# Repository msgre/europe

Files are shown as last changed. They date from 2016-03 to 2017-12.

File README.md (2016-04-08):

Europe is interactive knowledge game for children.

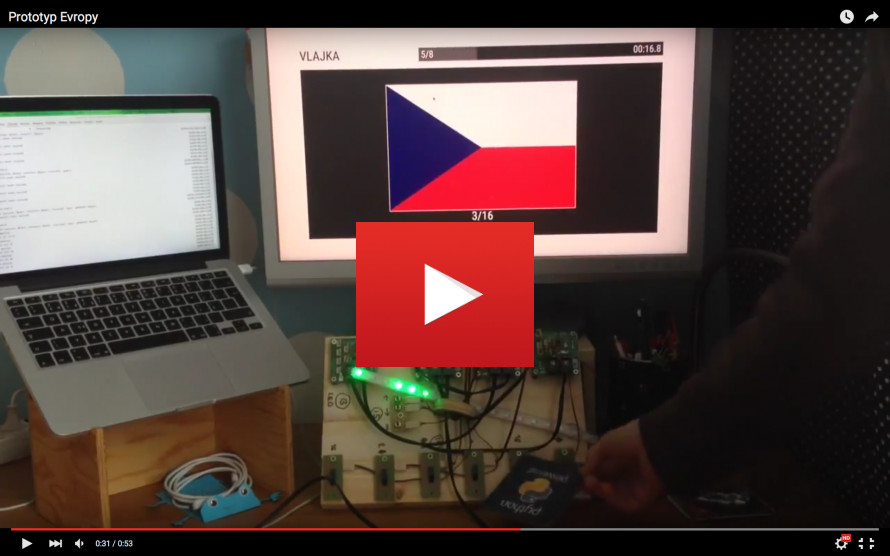
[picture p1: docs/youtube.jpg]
Europe prototype (https://youtu.be/zgLyUA2WT7c)


**Content**:

* [Construction](#construction)
    * [Gameboard](#gameboard)
    * [Hardware](#hardware)
    * [Software](#software)
    * [Design](#design)
    * [Content](#content)
* [Docker](#docker)
    * [Build](#build)
    * [Run](#run)
* [Application](#application)
    * [Game interface](#game-interface)
    * [Administration interface](#administration-interface)
* [Notes](#notes)
    * [Database initialization](#database-initialization)
    * [Coffeescript compilation](#coffeescript-compilation)
    * [LESS compilation](#less-compilation)
    * [Debug mode for Javascript application](#debug-mode-for-javascript-application)

# Construction

It is constructed from several parts:

* big wooden gameboard with map of Europe
* bunch of electronics
* software

## Gameboard

Board will be connected to the ground via spring, so children will be able to 
tilt it. Each european country will have gate on his territory. 

## Hardware

Each gate is constructed as optical sensor. On bottom part of board is 10
control boards, each of them capable to read state up to 6 sensors. Boards are
interconnected via ModBus.

There are additional 2 special boards -- one of them will serve as keyboard
(instead of optical sensors it will read state from buttons), second as 
controller of Neopixels RGB LED.

Details about hardware solution is stored in [`hardware/`](hardware) directory.

## Software

ModBus is connected through USB adapter to Intel NUC miniPC with Ubuntu Linux
and all necessary software:

* Django API backend
* Django Admin backend
* Python Watcher script, which read status from HW boards and send events
  through websocket connection to browser
* Frontend Javascript application build in Marionette framework

All components are dockerized and run behind Nginx proxy.

There are several subdirectories in regards to software part of this project:

* [`ansible/`](ansible)  
  Playbooks for bootstraping Ubuntu system (it will turn plain Ubuntu into 
  Evropa dedicated machine)
* [`europe/`](europe)  
  Django backend application, which realise API interface and administration
  for editing content (game questions)
* [`static/`](static)  
  Frontend Javascript application
* [`watcher/`](watecher)  
  Python3 application communicating with hardware (ModBus via USB) and implementing
  websockets server. Frontend Javascript application communicate with HW in
  real-time via messages sent over websocket.

## Design

Application design evolve in time. You could found some of the designs in 
[`screenshots/`](screenshots) directory. In [`layouts/`](layouts) is stored 
rough HTML version of early version application for easier CSS development.

## Content

Content of the game (questions about european countries) will be edited via
web administration. For easier development there are some of the content
store in directory [`content/`](content).

# Docker

There are several Dockerfiles in root directory, suffix indicate purpose of
file. Because there are lot of them, and running them manually from commandline
could be complicated, we use Docker Compose.

Main description is stored in [`docker-compose.yml`](docker-compose.yml).
According to [Docker Compose documentation](https://docs.docker.com/compose/extends/), 
there is standard way how to extend basic yml and adapt it to different
environments (notebook, Intel NUC, demo on Digital Ocean). This variants are
stored as `docker-compose.<ENV>.yml` files. To apply it, choose one, copy it or
make a named symlink `docker-compose.override.yml` (I personally use `devel`
variant on my notebook).

## Build

Run this commands:

    docker build -f Dockerfile.base -t msgre/common:europe-base.latest .
    docker-compose build
    cd watcher/ && docker build -t msgre/common:europe-watcher.latest .

`base` is general Django container, `watcher` take care about HW monitoring
and publish events on websockets.

## Run

    docker-compose up -d
    docker-compose logs

To kill and remove running containers, run:

    docker-compose kill && docker-compose rm -f

Beware! If you run Europe for first time, you must initiate database. See
[Database initialization](#database-initialization) below.

# Application

## Game interface

Open in **Chrome** browser URL http://192.168.99.100:8081/
(warning, doesn't work properly in Firefox due to disfunctional keyboard plugin).

For controling web app use following keys (they will be replaced in final 
product to real physical keys):

* `Q` = left
* `W` = right
* `P` = choice

During game phase, use:

* `0` = wrong answer
* `1` = right answer

If you run `watcher` container in debug mode, you could simulate HW events by
touching files in `watcher/gates` directory. For example:

    touch watcher/gates/14/1

will simulate ball passing gate number 1 on board 14. Same way you could 
simulate keyboard events.

## Administration interface

There is standard Django admin interface on http://192.168.99.100:8081/admin.
You could modify options, questions, and several other details about game.

# Notes

## Database initialization

Connect to already running `admin` container:

    docker exec -ti admin bash

Run following commands:

    ./manage.py migrate
    ./manage.py createsuperuser
    ./manage.py initial_questions /content
    ./manage.py fake_results

After this sequence, your DB schema will be up to date, and will contain
data about superadmin (to access administration via web interface), fake
results data (to bypass results pages with no entries) and initial set of
questions loaded from `content/` directory.

## Coffeescript compilation

First, check that you have CoffeeScript container. If no, build it:

    docker build -f Dockerfile.coffee -t msgre/common:coffee.latest .

One-time Coffeescript to Javascript compilation:

    docker run -ti --rm -v $PWD/static/app:/src msgre/common:coffee.latest -bc /src

Continuous compilation based on changes in watched directory:

    fswatch --exclude="\.js$" -o $PWD/static/app | xargs -n1 -I{} docker run -i --rm -v $PWD/static/app:/src msgre/common:coffee.latest -bc /src

## LESS compilation

One-time compilation:

    docker run -i --rm -v $PWD/static/css:/src ewoutp/lessc:latest /src/styles.less > $PWD/static/css/styles.css

## Debug mode for Javascript application

For debugging purposes you could add special URL parameters to directly enter
one of the Javascript application screens. In this case timeouts (part of code
that return you to initial `intro` page) will be set to very high value, so
you stay on given page for very long time (and you could debug HTML/CSS/JS 
things with peace in mind).

Enter URLs like `http://192.168.99.100:8081/?intro`. Last part after `?` 
character tells in which page you are interested. Enter one of this values:
`intro`, `crossroad`, `scores`, `gamemode`, `countdown`, `game`, `result`, 
`recap`, `score`.

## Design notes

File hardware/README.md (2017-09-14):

# Hardware

Europe's hardware consists of two boards -- gate and IR.

To detect active gate the IR board contains reflective IR photointerrupter.
This board has to be powered by 5 VDC, the output signal is 5V (no activity)
or 0V (GND, gate was activated).

Up to six IR boards can be connected to one "gate board". This board can supply
5V to all connected IR gates and register their output signal. Gate board have
to be powered by 5VDC from RS485 bus. The Modbus is used to read status of all
IR gates connected to one gate board.

Each gate board has 4 solder jumpers for Modbus slave address. Their
firmware can be updated via Modbus.

## Overview

- `eagle`, `gerber` and `pdf` -- documentation for manufacturing this hardware.
- `bootloader` -- source code of Modbus bootloader for ATMegaXX8P.
- `src` -- main firmware for gate boards.
- `neopixel` -- control Neopixel (WS2812) LEDs via Modbus.
- `examples` -- simple Python examples, how to control and update gates over Modbus.

## Bootloader and Firmware

To make firmware for AVR the avr-gcc and avrdude is needed. Bootloader and firmware
can be compiled by `make`.

Programming bootloader to connected board (you will need AVRispmkII programmer):

    $ cd bootloader
    $ make
    $ make fuses && make flash

If programming was successful, the green onboard LED should be permanently turned on.
This indicates the bootloader is running and accepting Modbus commands.

Main firmware can be compiled like this:

    $ cd src
    $ make

This will create `main.bin` file which can be used with Modbus bootloader like
this:

    $ ./examples/modbus_update.py /dev/usbserial.XYZ addr ./src/main.bin

## Neopixel Firmware

Special firmware version for interfacing WS2812 LEDs through Modbus is
in directory `neopixel`. This firmware can be compiled the same way as main
firmware:

    $ cd neopixel
    $ make

This special firmware has the same modbus registers as main firmware (inputs,
reset, HW&FW version) and aditional address space `0x1000`. One register in
this space represents one Neopixel LED. The bit mapping is:

    +-------------------------------+-------------------------------+
    |         High byte             |            Low byte           |
    +-------------------------------+-------------------------------+
    | 7 | 6 | 5 | 4 | 3 | 2 | 1 | 0 | 7 | 6 | 5 | 4 | 3 | 2 | 1 | 0 |
    +-------------------------------+-------------------------------+
    | L | L | L | L | R | R | R | R | G | G | G | G | B | B | B | B |
    +-------------------------------+-------------------------------+

where `R` = red, `G` = green, `B` = blue, `L` = brightness. For example:

    0x1F00 = red
    0x10F0 = green
    0x100F = blue
    0x16F0 = yellow
    0x06F0 = yellow, minimum brightness.
    0xF6F0 = yellow, maximum brightness.

Neopixels should be connected to the pin PWM0 (AVR pin PD6).

## Modbus Address

The slave address is selected by solder jumpers SJ1-SJ4. Soldered jumper represent
LOW, thus connecting SJ3 and SJ4 makes address `0x03`.

The bootloader slave address has MSB set -- for example `0x03 -> 0x83`.

## Modbus Registers

Modbus register is 16 bit integer. The firmware has three registers on addresses:

- `0x0000` 0x00XX; IR gates state since last Modbus reading or FW reset.
- `0x0001` 0xXYYY; firmware (Y) and hardware (X) version
- `0x0002` reset; any writes to this register will trigger FW reset in 500ms.

## Python Examples

Tested with Python 2.7, pyserial 3.0.1 and minimalmodbus 0.7.

    $ pip install pyserial
    $ pip install minimalmodbus

To update firmware in board with slave address 15 (0x0F), bootloader address is
143 (0x8F):

    $ cd ./examples
    $ ./modbus_update.py /dev/usbserial.XYZ 15 ./firmware.bin

To read latest gate states from board with slave address 15 (0x0F):

    $ ./examples/modbus_read.py /dev/usbserial.XYZ 15

Slave dicovery on bus can be done by:

    $ ./examples/modbus_discover.py /dev/usbserial.XYZ

To use neopixel firmware on slave 13 (example expects 24 WS2812 LEDs):

    $ ./examples/neopixel_rainbow.py /dev/usbserial.XYZ 13

## Wires

There are two types of wires.

First wire is for RS485/Modbus and connects
together gate boards. This should be at least 2 twisted pairs with RJ12 (6p6c) on both
ends. All gate boards are daisy chained from first to last board and to Modbus
master.

Second type of wire connects IR boards with gate boards. This is 3 core flat
cable and 3 pins connectors with 2.54mm (0.1'') pitch. KK254 Molex or NS25 Ninigi
types can be used.

### RS485/Modbus Wires

The cable for RS485 is Ethernet Cat 5e, stranded. Orange and orange/wite pair is not used.

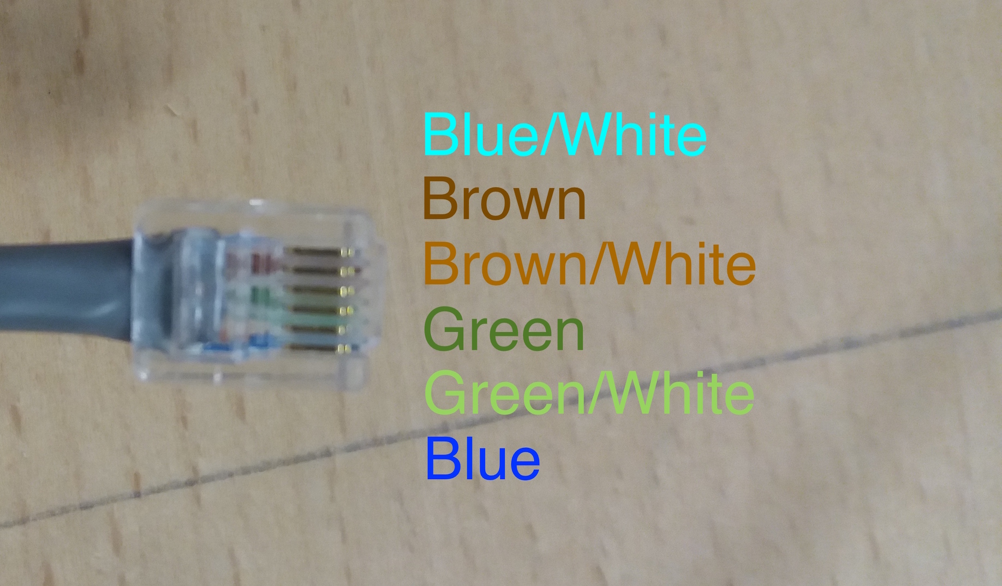
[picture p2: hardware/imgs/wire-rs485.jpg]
RS485 cable with RJ12 connector


### IR Boards Wires

Prepare flat wire, connector housing and pins.

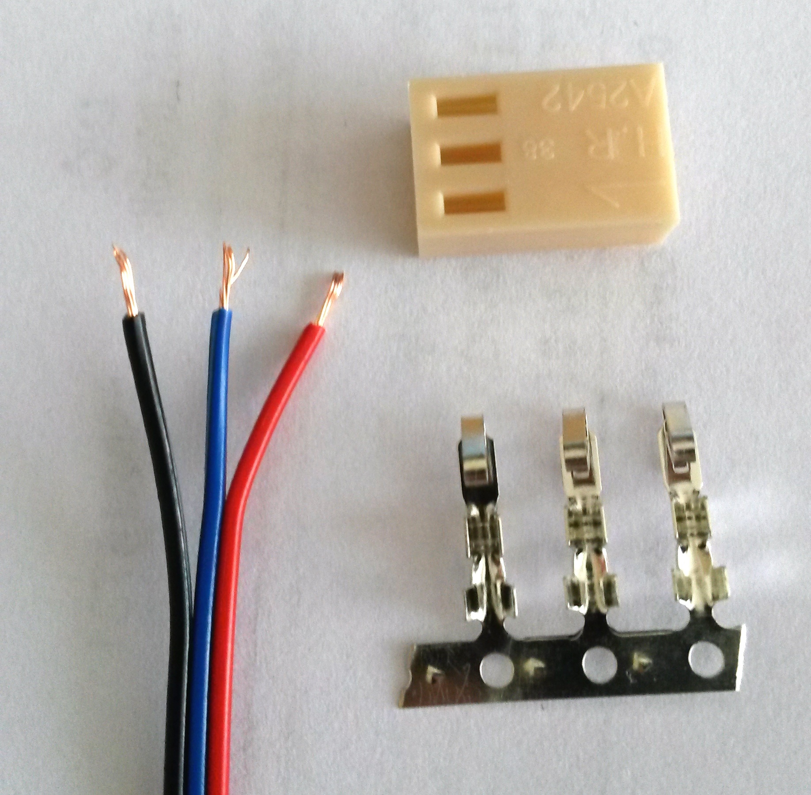
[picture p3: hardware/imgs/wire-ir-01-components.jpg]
IR wire components


Crimp pins to wire on both ends. Used crimping tool: Engineer PA-09.

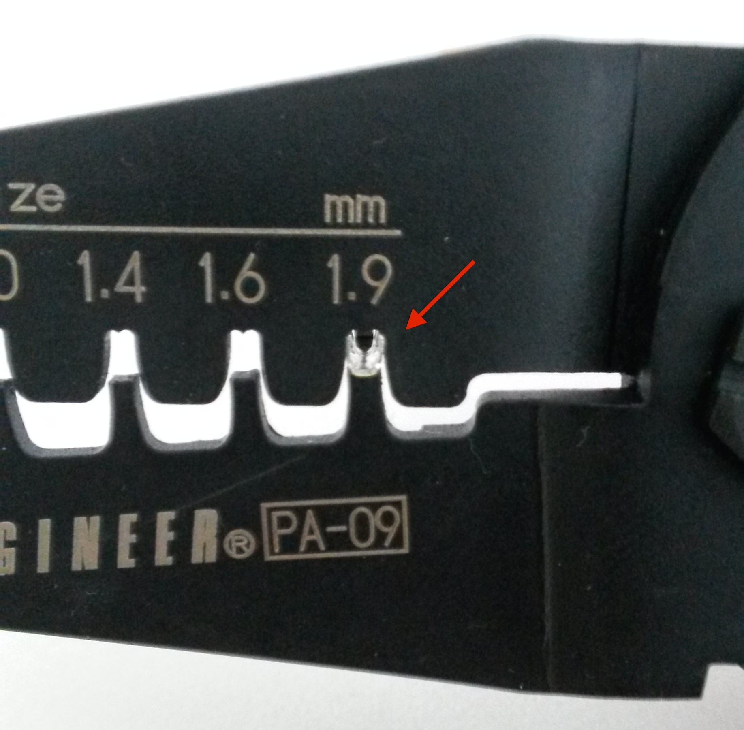
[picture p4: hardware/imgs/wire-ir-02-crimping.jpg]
IR wire crimping tool


Correct pins orientation on wire.

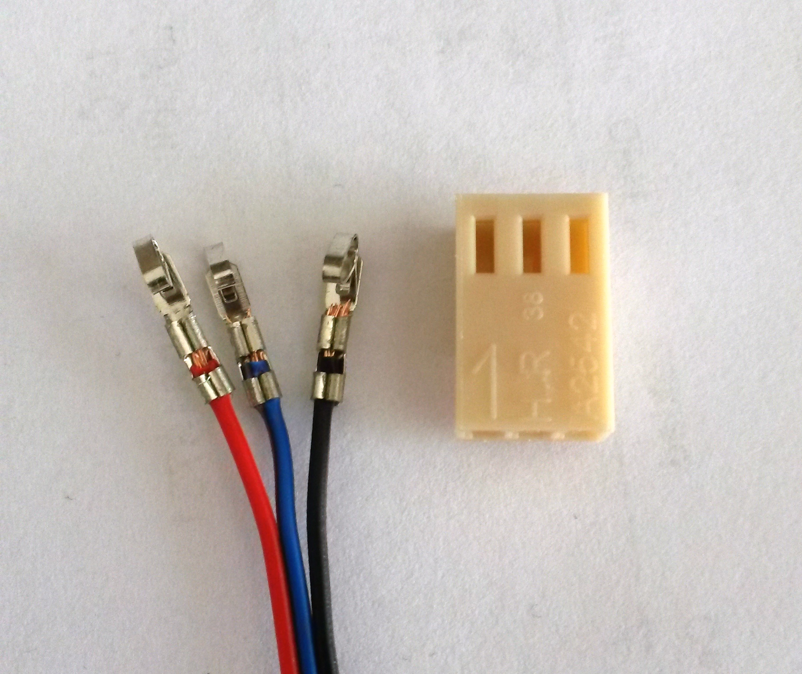
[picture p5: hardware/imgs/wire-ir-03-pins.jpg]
IR wire with pins


Finished wire.

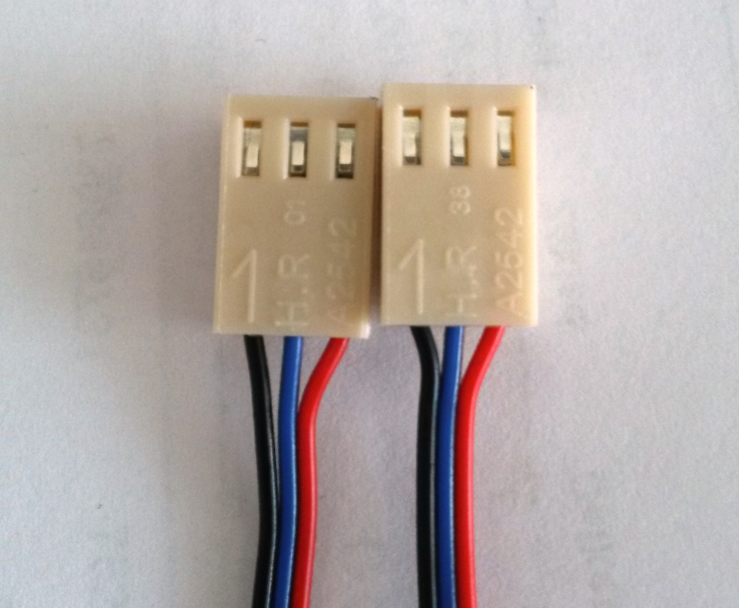
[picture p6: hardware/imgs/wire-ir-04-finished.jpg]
Finished IR wire


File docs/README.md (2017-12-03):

# Main documentation

Stored on Google docs: 
https://docs.google.com/document/d/1SYrjAHexw3LlzOskLTjt9yeirrrmdV1CG6Bf5Hr2Jm0/edit

# Timelog

Programming

* 2 days, API design and implementation of first rough version, February 2015
* 4 days, Javascript application, iteration between JS and API backend,
  February/March 2015
* 8 days, Second major iteration, fully functional demo without MQTT
  capabilities, January 2016

Planing, preparations

* around 3 days

# Photos

* `bottom/`
  Bottom part of boardgame. You could find there location of individual boards, gates and wiring.

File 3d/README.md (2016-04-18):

# Models for 3D Print

Some parts of the Gameboard required custom made pieces printed on a 3D printer.

Here are 3D models from Fusion 360 `*.f3d` and exported STL `*.stl` files for slicing software.

* Sensor Cover - cover for an optical sensor below the Gameboard's optical gates
* Reflector Holder - holder for a small reflector with NeoPixel RGB LED

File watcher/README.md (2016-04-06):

Demonstration of WebSocker communication between server side code connected 
directly to gate hardware and frontend Javascript code in browser.

This is not final version of watcher application. There are still commented
parts in code, because there are still plenty work in progress. But core 
functionality is working (websocket communication between browser/server,
communication with boards through ModBus).

# Setup

You will need NUC minipc with Ubuntu, ModBus adapter, few gates connected
together and http access to NUC.

Then follow this steps:

1) Build Docker image:

        docker build -t msgre/common:europe-watcher.latest .

2) Run Docker image:

        docker run -ti --rm --name watcher --device /dev/ttyUSB0 -p 8082:8082 msgre/common:europe-watcher.latest

   You must provide access to physical ModBus adapter usualy mounted to 
   `/dev/ttyUSBX` and expose port 8082 to HTML demo page.

   There is also DEBUG mode in case you have no access to physical devices:

        docker run -ti --rm --name watcher -e DEBUG=1 -v $PWD/gates:/root/gates -p 8082:8082 msgre/common:europe-watcher.latest

   For details about DEBUG mode see below.

3) Open web browser
   Put there URL of NUC (in my case something like http://192.168.0.113:8082/).
   Open web developer javascript console and try press some button on keyboard
   gate (you should see published events from watcher). If you run
   `window.eu_session.publish('com.europe.start', [1]);` command in console
   you will enable gates. From now you should see also events about ball passing
   gates.

# Data format

Messages from `watcher`:

* `com.europe.keyboard`
  - you will receive code with button pressed
  - keyboard gate is technically same as normal gate; it's up to you how you
    configure physical buttons -- each button have own bit (see bellow)
* `com.europe.gate`
  - you will receiver object
  - keys represent gate code (1-16)
  - value represent crossed gates, each bit represent individual gate (see bellow)

Messages for `watcher`:

* `com.europe.effect`
  - turn on some of the LED effect on main gamebord
  - you must provide code representing mode
  - TODO: describe modes
* `com.europe.light`
  - switch on particular LED on main gamebord
  - you must provide 2 parameters: LED order number and color
  - addressed LED will blink 3 times and then stay in switch on state
* `com.europe.start`
  - start watching of game gates (from this time `com.europe.gate` events will 
    be published)
  - provide any value (it is ignored)
* `com.europe.stop`
  - stop watching of game gates
  - provide any value (it is ignored)

# DEBUG mode

For easier debugging of websockets communication, you could turn on DEBUG mode 
on watcher script. In this mode, container will be watching directory ~/gates
and looking for structure like:

    ~/gates/<GATE_NUMBER>/<GATE_STATUS>

Where:

    <GATE_NUMBER> is directory in form of integer number, defining specific gate
    <GATE_STATUS> is empty file which filename represent gate status

For example file on path `~/gates/14/1` will be emited as ball passing gate
`1` on board `14`.

You could map directory `~/gates` into container from your host machine, and
then simulate traffic on gameboard by invoking simple touch commands:

    touch ~/gates/14/1

After each read over `~/gate` directory, all founded files will be deleted.

## Gate mapping

Each gate is capable of watching 6 gates. If you look on board from above,
you will see 6 connectors. They are mapped to individual bits of 16 bit value:
        
        [04] [08]
     [01] [02] [10] [20]

For example when ball pass gate 01, you will get value 1. When ball pass gate 20,
you will get value 32.
Board could give you combined value, for example if 2 mentioned gates are crossed 
in nearly same time, you will get value 33 (it is nonsense from game perspective,
but technically it is possible).

# Behaviour of Neopixel's LED

In normal mode, Neopixel's LEDs are controlled during the game (effects on
intro page, countdown, during the game, etc).

Neopixels have noticeable current consumption, which leads time to time to
unstability of clustered boards. There is "emergency" environment variable
for situations like this.

Run container with variable LED_OFF=1 and all Neopixels effects will be disabled.

## Demos

For debugging purposes, all Neopixels effects are available through neopixels.py
library. Just run:

    python neopixels.py <EFFECT> <COM> <SLAVE>

where:

    <EFFECT> is name of Neopixels effect you want to see
    <COM> is path to USB ModBus device
    <SLAVE> is number of gate controlling neopixels

For example:

    python neopixels.py rainbow /dev/ttyUSB0 13

# Issues

On OSX Docker run inside Virtualbox machine, so there is one more layer to beat.
If you connect ModBus adapter into USB on Mac, you will see device like
`/dev/tty.usbserial-AJ03KXCG`. When I provide access for docker container
through `--device` switch, this device will be mapped to `/dev/ttyUSBX` in 
docker machine (to be sure, go into docker machine and check it: 
`docker-machine ssh` and `ls -l /dev | grep -i usb`), but you must allow access 
to USB device in VirtualBox IDE.

Even after this arrangement code was unstable (even with `--privileged` switch). 
For me it was easier move to physical NUC and develop code directly on production
hardware.

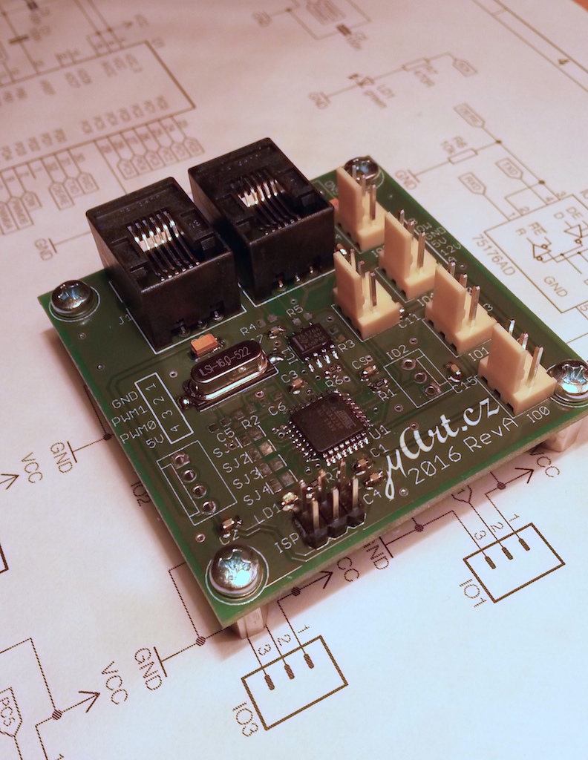
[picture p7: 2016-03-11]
hardware/imgs/eu-gate.jpg

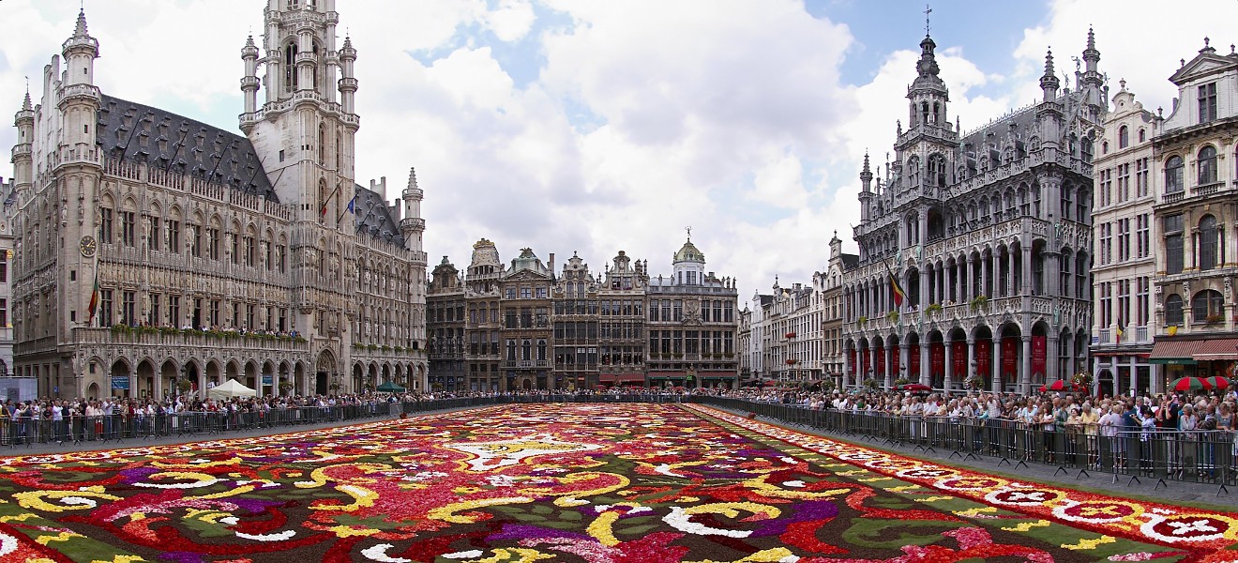
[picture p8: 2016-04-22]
static/img/brusel.jpg

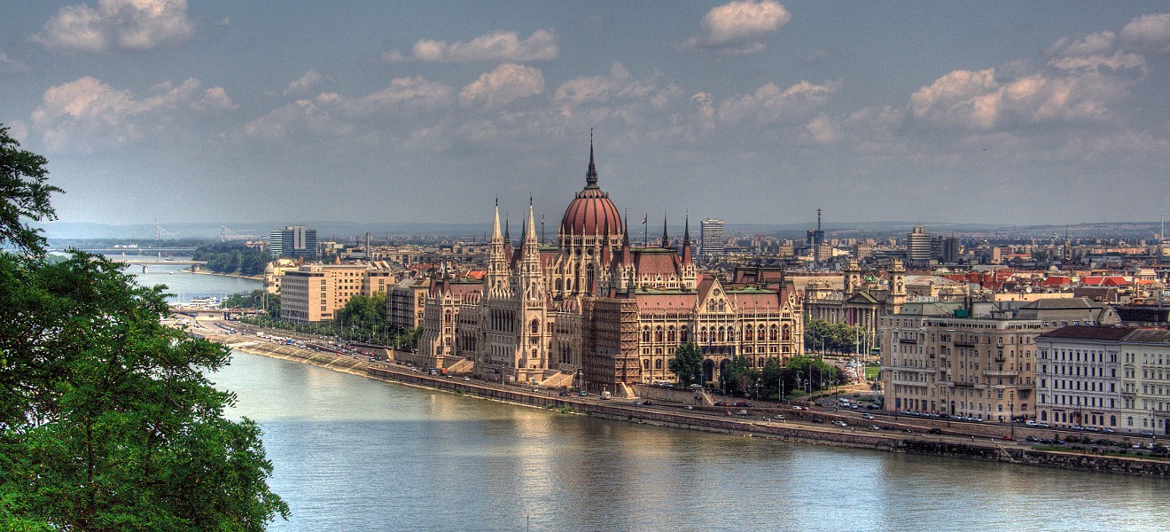
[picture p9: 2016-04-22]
static/img/budapest.jpg

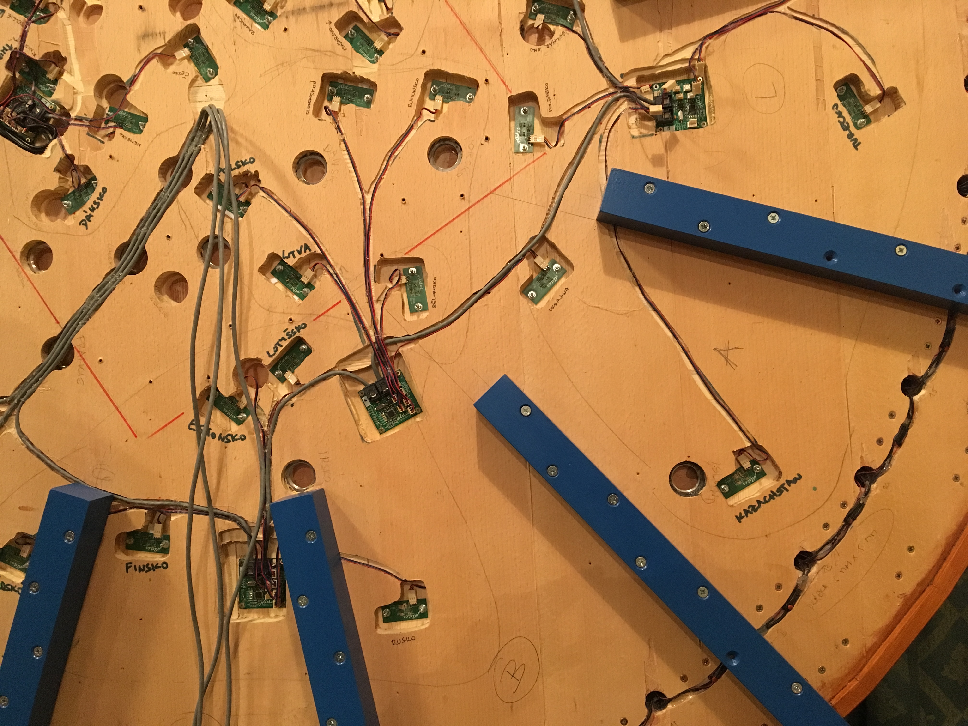
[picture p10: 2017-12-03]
docs/bottom/right_bottom.jpg

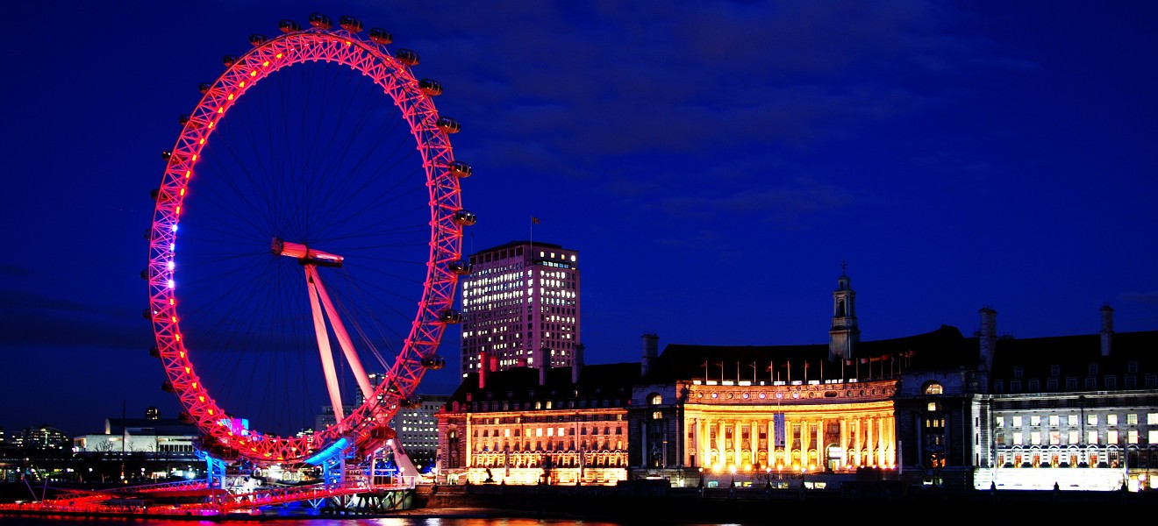
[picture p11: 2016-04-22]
static/img/london.jpg

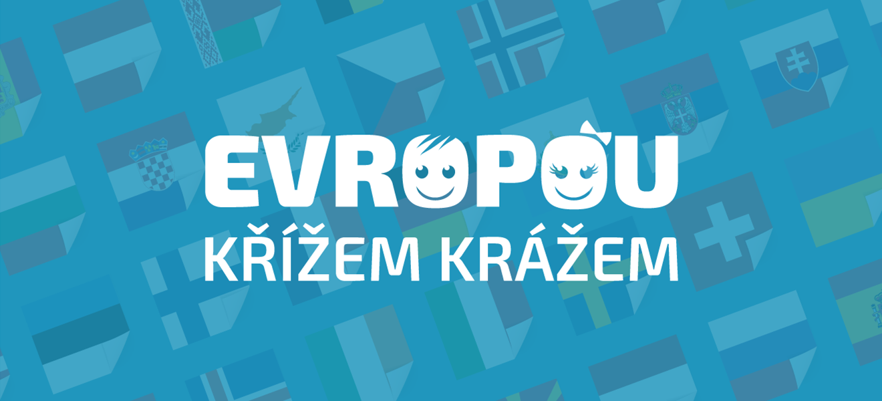
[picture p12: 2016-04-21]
static/img/titul1.png

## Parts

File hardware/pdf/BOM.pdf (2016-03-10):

File: | eu-gate, revA
Date: | 23JAN16
Note: | BOM for gate boards
Part | Pcs | Value | Package | Note | URL
C1-C4, C7, C9-C15 | 12 | 100nF | SMD 0603 | 16V; X7R; ±10% | http://www.tme.eu/cz/details/cl10b104ko8nnnc/kondenzatory-mlcc-smd-0603/samsung/
C5, C6 | 2 | 18pF | SMD 0603 | 50V; C0G; ±1% | http://www.tme.eu/cz/details/cl10c180fb8nnnc/kondenzatory-mlcc-smd-0603/samsung/
C8, C16 | 2 | 10uF | SMD A | tantal, 16V, ±10% | http://www.tme.eu/cz/details/t491a106k016at/tantalove-kondenzatory-smd/kemet/
IC1 | 1 | SN75176AD | SO8 | | http://www.tme.eu/cz/details/sn75176ad/integr-obvody-interface-rs232422485/texas-instruments/
IC1 | 1 | SN75176BD | SO8 | substitute | http://www.tme.eu/cz/details/sn75176bd/integr-obvody-interface-rs232422485/texas-instruments/
IO0-IO5 | 6 | KK 254, 1x3 | THT | | http://www.tme.eu/cz/details/ns25-w3p/signalove-konektory-raster-254mm/ninigi/
ISP | 1 | 2x3, 2.54mm | THT | | http://www.tme.eu/cz/details/zl202-6g/konektory-hrebinky/connfly/ds1021-2_3sf1-1/
J1, J2 | 2 | RJ12 | THT | 6p6c | http://www.tme.eu/cz/details/mx-95501-2661/konektory-rj/molex/95501-2661/
J3 | 1 | KK 254, 1x2 | THT | | http://www.tme.eu/cz/details/mx-22-23-2021/signalove-konektory-raster-254mm/molex/22-23-2021/
J4 | 1 | KK 254, 1x4 | THT | | http://www.tme.eu/cz/details/mx-47053-1000/signalove-konektory-raster-254mm/molex/47053-1000/
LD1 | 1 | green | SMD 0603 | OSG50603C1E | http://www.tme.eu/cz/details/osg50603c1e/diody-led-smd-barevne/optosupply/
Q1 | 1 | 16MHz | SMD, HC49USM | ±30ppm; 18pF | http://www.tme.eu/cz/details/hc49usm-ff3f16.00/kremikove-rezonatory-smd/ilsi/hc49usm-ff3f18-160000/
R1, R6 | 2 | 10kΩ | SMD 0603 | 0,1W; ±5% | http://www.tme.eu/cz/details/rc0603jr-0710k/rezistory-smd-0603/yageo/rc0603jr-0710kl/
R2 | 1 | 1MΩ | SMD 0603 | 0,2W; ±5% | http://www.tme.eu/cz/details/hp03-1m5%25/rezistory-smd-0603/royal-ohm/hp03w5j0105t5e/
R3 | 1 | 120Ω | SMD 0603 | 0,1W; ±5% | http://www.tme.eu/cz/details/rc0603jr-07120r/rezistory-smd-0603/yageo/rc0603jr-07120rl/
R4, R5 | 2 | 4.7kΩ | SMD 0603 | 0,1W; ±5% | http://www.tme.eu/cz/details/crcw06034k70jnea/rezistory-smd-0603/vishay/
R7 | 1 | 470kΩ | SMD 0603 | 0,2W; ±5% | http://www.tme.eu/cz/details/hp03-470r5%25/rezistory-smd-0603/royal-ohm/hp03w5j0471t5e/
SJ1-SJ4 | 4 | - | - | jumper, solder
U1 | 1 | ATMega88PA | TQFP32 | | http://www.tme.eu/cz/details/atmega88pa-au/mikroprocesory-atmel-avr-smd/atmel/

Lines with gray background are not mounted on DPS

## Gate

File: | IR, RevA
Date: | 06.03.16
Note: | reflective IR boards
Part | Pcs | Value | Package | Note | URL
C1 | 1 | 100nF | SMD 0603 | 16V; X7R; ±10 | http://www.tme.eu/cz/details/cl10b104ko8nnnc/kondenzatory-mlcc-smd-0603/samsung/
J1 | 1 | KK 254, 1x3 | THT, 90 | Ninigi | http://www.tme.eu/cz/details/ns25-w3k/signalove-konektory-raster-254mm/ninigi/
R1, R3 | 2 | 10kΩ | SMD 0603 | 0,1W; ±5% | http://www.tme.eu/cz/details/rc0603jr-0710k/rezistory-smd-0603/yageo/rc0603jr-0710kl/
R2, R4 | 1 | 220Ω | SMD 0603 | 0,1W; ±5% | http://www.tme.eu/cz/details/rc0603jr-07220r/rezistory-smd-0603/yageo/rc0603jr-07220rl/
U1 | 1 | LTH-209-01 | THT | | http://www.tme.eu/cz/details/lth209-01/opticka-cidla-pro-plosne-spoje/liteon/lth-209-01/
Q2 | 1 | BC847 | SMD | | http://www.tme.eu/cz/details/bc847ae6327/tranzistory-npn-smd/infineon-technologies/

Lines with gray background are not mounted on DPS

IR

File: | Wires for IR boards
Date: | 08MAR16
Note: | 6x40 cm, 16x30 cm, 26x20 cm
Part | Pcs | Note | URL
NS25-T | 300 | pin for Ninigi connector | http://www.tme.eu/cz/details/ns25-t/signalove-konektory-raster-254mm/ninigi/
NS25-G3 | 100 | housing for Ninigi, 3 pins | http://www.tme.eu/cz/details/ns25-g3/signalove-konektory-raster-254mm/ninigi/
Wire | | 3 core flat cable
File: | Modbus wire for Gate boards
Date: | 08MAR16
Note: | 1x20 cm, 2x25 cm, 1x30 cm, 4x35 cm, 1x40 cm, 1x85 cm
Part | Pcs | Note | URL
RJ12W | 20 | RJ12, 6p6c | http://www.tme.eu/cz/details/rj12w/konektory-rj/ninigi/
Wire | | 2 or more twisted pairs

## Wires

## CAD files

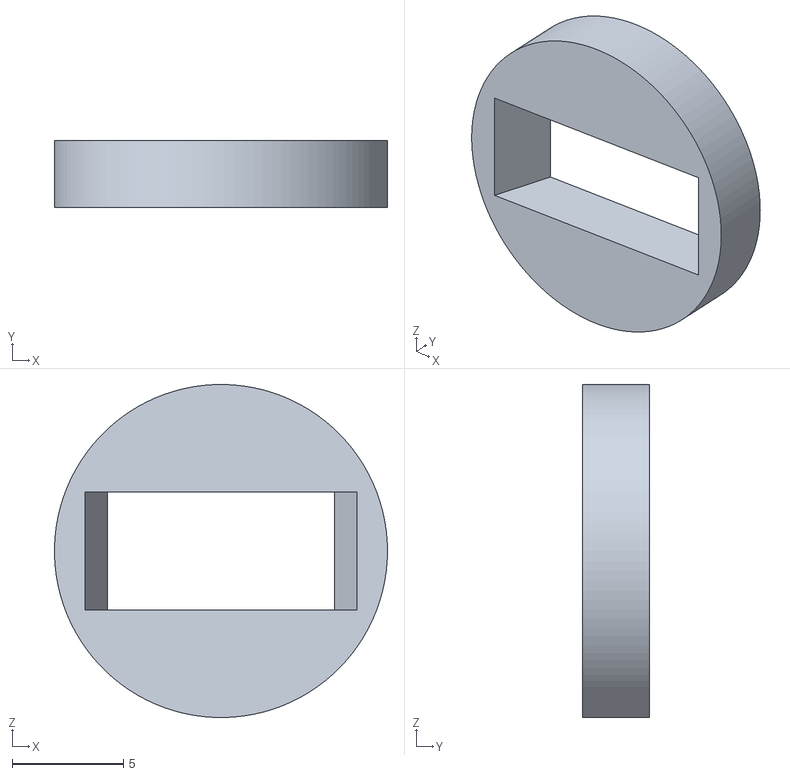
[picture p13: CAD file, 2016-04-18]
3d/sensor-cover.stl
15.0 x 3.00 x 15.0

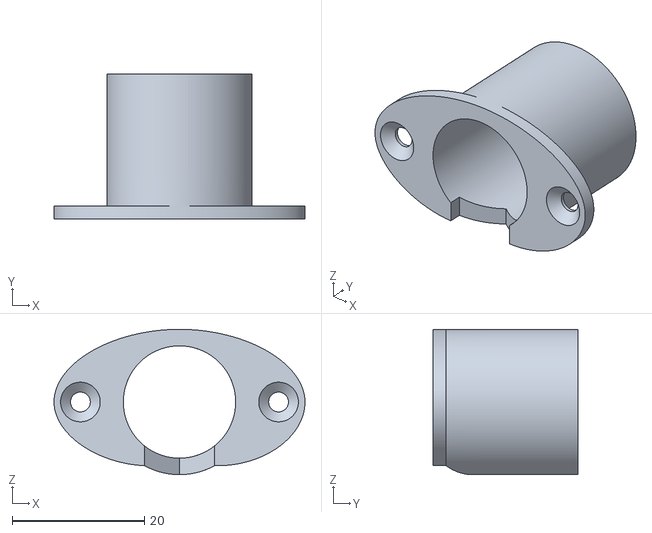
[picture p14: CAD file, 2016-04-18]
3d/reflector-holder.stl
38.0 x 22.0 x 22.0

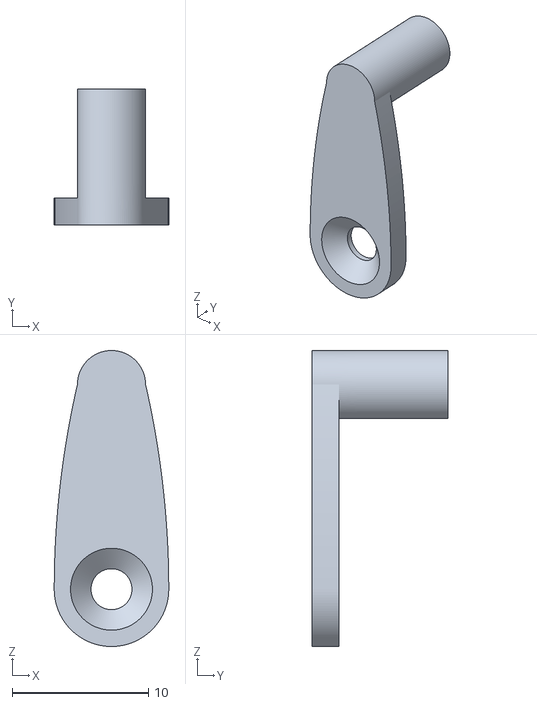
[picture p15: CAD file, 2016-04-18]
3d/reflector-holder-pin.stl
8.40 x 10.0 x 21.7

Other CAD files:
3d/reflector-holder.f3d
3d/sensor-cover.f3d

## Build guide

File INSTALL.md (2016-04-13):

Europe project run on Intel NUC mini PC. Follow this instruction to prepare
NUC machine for our application.

# Ubuntu installation on NUC

* Download image ubuntu-14.04.4-desktop-amd64 on Ubuntu site.
* Put empty USB disk into computer and run UNetbootin application. Choose 
  downloaded image and prepare USB disk (this step take ~10 minutes)
* Put USB into NUC, turn on and select Boot options according to
  http://cdn.arstechnica.net/wp-content/uploads/2014/01/BIOS.png
  - Secure boot: Disabled
  - Secure boot mode: Standard
  - Platform Key (PKpub): Not Installed
  - Key Exchange Key (KEK): Installed
  - Signature Database (db): Installed
  - Blacklisted Signature Database (dbx): Installed
* Connect NUC to Enthernet and boot from USB
* Install Ubuntu:
  - Grub: Install Ubuntu
  - Language: English
  - [x] Download updates while installing
    [x] Install 3rd party software
  - Erase disk and install Ubuntu
    (partition #1 sda EFIboot, partition #2 sda etx4, partition #4 sda swap)
  - Timezone: Prague
  - Keyboard: English (US)
  - Your name: europe
    Computer name: europe
    Username: europe
    [x] Log in automatically
* After installation process, reboot Ubuntu and eject USB drive
* Launch Software updater and update system
* Install SSH server via terminal: `sudo apt-get install openssh-server`
* Set System Settings:
  - Brightness & Lock
    - Turn screen off when inactive for: Never
    - Lock: OFF
    - [ ] Require my password when waking from suspend
  - Software & Updates
    - Updates tab
      - Automatically check for updates: Never
* Note IP address of machine: `ifconfig eth0` and follow with Ansible described 
  bellow

Further information about Ubuntu installation on NUC: 
http://arstechnica.com/gadgets/2014/02/linux-on-the-nuc-using-ubuntu-mint-fedora-and-the-steamos-beta/

# Run Ansible playboook

Ansible is tool for easy system provisioning and application deployment.
We use it for installing all necessary SW on Ubuntu, configuration and 
deployment of application.

Prerequisities: You will need Ansible version 1.7.1

Steps:

* Put you public SSH `id_rsa.pub` key into `/home/europe/.ssh/authorized_keys` 
  on NUC machine (beware, directory `/home/europe/.ssh` must be set to `0700` 
  mode)
* Repeat it for `/home/root` folder (yes, we are now allowing remote root
  access to machine)
* Go into [`ansible/`](ansible) directory, copy file `hosts.example` to `hosts`
  and replace string `<IP_ADDRESS_OF_YOUR_MACHINE>` to your NUC IP (see last 
  step in [Ubuntu installation on NUC](#ubuntu-installation-on-nuc) section)
* Run command: `ansible-playbook bootstrap.yml -i hosts`

When playbook finish, logout from Unity desktop environment. You will see login
screen with input field for password. Next to it on right side is white circle.
Click on it and change it to LXDE.

# Notes

## Switch back to Unity environment

* open terminal with CTRL+ALT+T shortcut
* run command `lxpanel --profile LXDE` -- you will see bar on bottom of the 
  screen with logout button
* logout
* on login screen change environment back to Unity (click on white circle)

## Switch to text terminal

Press CTRL+ALT+F1 shortcut to go away from GUI to text terminal.

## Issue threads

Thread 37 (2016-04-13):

Docker daemon nestartuje pokud je network down

msgre, 2016-04-13:
```
INFO[0001] Loading containers: done.
INFO[0001] Daemon has completed initialization
INFO[0001] Docker daemon                                 commit=20f81dd execdriver=native-0.2 graphdriver=aufs version=1.10.3
INFO[0001] API listen on /var/run/docker.sock
ERRO[0006] external resolution failed, dial udp 8.8.8.8:53: connect: network is unreachable
ERRO[0006] external resolution failed, dial udp 8.8.4.4:53: connect: network is unreachable
ERRO[0011] external resolution failed, dial udp 8.8.8.8:53: connect: network is unreachable
ERRO[0011] external resolution failed, dial udp 8.8.4.4:53: connect: network is unreachable
ERRO[0016] external resolution failed, dial udp 8.8.8.8:53: connect: network is unreachable
ERRO[0016] external resolution failed, dial udp 8.8.4.4:53: connect: network is unreachable
INFO[0026] No non-localhost DNS nameservers are left in resolv.conf. Using default external servers : [nameserver 8.8.8.8 nameserver 8.8.4.4]
INFO[0026] IPv6 enabled; Adding default IPv6 external servers : [nameserver 2001:4860:4860::8888 nameserver 2001:4860:4860::8844]
INFO[0856] Processing signal 'terminated'
Waiting for /var/run/docker.sock
INFO[0000] [graphdriver] using prior storage driver "aufs"
INFO[0000] Graph migration to content-addressability took 0.00 seconds
INFO[0000] Firewalld running: false
/var/run/docker.sock is up
INFO[0000] Default bridge (docker0) is assigned with an IP address 172.17.0.0/16. Daemon option --bip can be used to set a preferred IP address
WARN[0000] Your kernel does not support swap memory limit.
INFO[0000] Loading containers: start.
.....INFO[0000] No non-localhost DNS nameservers are left in resolv.conf. Using default external servers : [nameserver 8.8.8.8 nameserver 8.8.4.4]
INFO[0000] IPv6 enabled; Adding default IPv6 external servers : [nameserver 2001:4860:4860::8888 nameserver 2001:4860:4860::8844]
INFO[0000] No non-localhost DNS nameservers are left in resolv.conf. Using default external servers : [nameserver 8.8.8.8 nameserver 8.8.4.4]
INFO[0000] IPv6 enabled; Adding default IPv6 external servers : [nameserver 2001:4860:4860::8888 nameserver 2001:4860:4860::8844]
INFO[0000] No non-localhost DNS nameservers are left in resolv.conf. Using default external servers : [nameserver 8.8.8.8 nameserver 8.8.4.4]
INFO[0000] IPv6 enabled; Adding default IPv6 external servers : [nameserver 2001:4860:4860::8888 nameserver 2001:4860:4860::8844]
INFO[0000] No non-localhost DNS nameservers are left in resolv.conf. Using default external servers : [nameserver 8.8.8.8 nameserver 8.8.4.4]
INFO[0000] IPv6 enabled; Adding default IPv6 external servers : [nameserver 2001:4860:4860::8888 nameserver 2001:4860:4860::8844]

INFO[0001] Loading containers: done.
INFO[0001] Daemon has completed initialization
```

msgre, 2016-04-13:
A dalsi neprijemnost -- Chromium nejak detekuje stav site a pokud se nahodi, tak sam vyvola reload stranky (tj. kdyz dockery nastartuji pozdeji nez prohlizec, objevi se v nem sice hlaska o nedostupnosti webu, ale ta po chvilce sama zmizi az sit najede). Nic takoveho se ale nedeje, pokud uz pred startem aisny odpoji ethernetovy kabel.

msgre, 2016-04-18:
```
root@europe:/var/log/upstart# cat docker.log
Waiting for /var/run/docker.sock
time="2016-04-18T11:01:17.806747899+02:00" level=info msg="New containerd process, pid: 30730\n"
/var/run/docker.sock is up
time="2016-04-18T11:01:18.916347788+02:00" level=info msg="Graph migration to content-addressability took 0.00 seconds"
time="2016-04-18T11:01:18.955759266+02:00" level=info msg="Firewalld running: false"
time="2016-04-18T11:01:19.043958171+02:00" level=info msg="Default bridge (docker0) is assigned with an IP address 172.17.0.0/16. Daemon option --bip can be used to set a preferred IP address"
time="2016-04-18T11:01:19.183038090+02:00" level=warning msg="Your kernel does not support swap memory limit."
time="2016-04-18T11:01:19.183443957+02:00" level=warning msg="mountpoint for pids not found"
time="2016-04-18T11:01:19.183835150+02:00" level=info msg="Loading containers: start."

time="2016-04-18T11:01:19.183956924+02:00" level=info msg="Loading containers: done."
time="2016-04-18T11:01:19.183985281+02:00" level=info msg="Daemon has completed initialization"
time="2016-04-18T11:01:19.184018586+02:00" level=info msg="Docker daemon" commit=4dc5990 graphdriver=aufs version=1.11.0
time="2016-04-18T11:01:19.204622444+02:00" level=info msg="API listen on /var/run/docker.sock"
time="2016-04-18T11:04:38.104513898+02:00" level=info msg="No non-localhost DNS nameservers are left in resolv.conf. Using default external servers : [nameserver 8.8.8.8 nameserver 8.8.4.4]"
time="2016-04-18T11:04:38.104543263+02:00" level=info msg="IPv6 enabled; Adding default IPv6 external servers : [nameserver 2001:4860:4860::8888 nameserver 2001:4860:4860::8844]"
time="2016-04-18T11:04:38.581446660+02:00" level=info msg="Layer sha256:b4a4ff9178b94ec40b0074c65abeeb15afda198c034f886f59fa65aa2cd27e14 cleaned up"
time="2016-04-18T11:04:38.714729400+02:00" level=info msg="Layer sha256:b4a4ff9178b94ec40b0074c65abeeb15afda198c034f886f59fa65aa2cd27e14 cleaned up"
time="2016-04-18T11:04:38.851823143+02:00" level=info msg="Layer sha256:b4a4ff9178b94ec40b0074c65abeeb15afda198c034f886f59fa65aa2cd27e14 cleaned up"
time="2016-04-18T11:04:38.990436900+02:00" level=info msg="No non-localhost DNS nameservers are left in resolv.conf. Using default external servers : [nameserver 8.8.8.8 nameserver 8.8.4.4]"
time="2016-04-18T11:04:38.990469814+02:00" level=info msg="IPv6 enabled; Adding default IPv6 external servers : [nameserver 2001:4860:4860::8888 nameserver 2001:4860:4860::8844]"
time="2016-04-18T11:06:41.169898689+02:00" level=info msg="Layer sha256:8cedefadc045ecd375d2644ccbaf7d05afb07b6fed4c806f6c8442b54d5388a1 cleaned up"
time="2016-04-18T11:06:41.312228846+02:00" level=info msg="No non-localhost DNS nameservers are left in resolv.conf. Using default external servers : [nameserver 8.8.8.8 nameserver 8.8.4.4]"
time="2016-04-18T11:06:41.312272339+02:00" level=info msg="IPv6 enabled; Adding default IPv6 external servers : [nameserver 2001:4860:4860::8888 nameserver 2001:4860:4860::8844]"
time="2016-04-18T11:06:46.754209616+02:00" level=info msg="Layer sha256:8830668ccf7ecd42e91eb02a0dbe6587273747d00e9399b3c46b0259809b145f cleaned up"
time="2016-04-18T11:06:47.733772803+02:00" level=info msg="Layer sha256:8cedefadc045ecd375d2644ccbaf7d05afb07b6fed4c806f6c8442b54d5388a1 cleaned up"
time="2016-04-18T11:06:47.861841411+02:00" level=info msg="Layer sha256:8cedefadc045ecd375d2644ccbaf7d05afb07b6fed4c806f6c8442b54d5388a1 cleaned up"
time="2016-04-18T11:06:48.802270272+02:00" level=info msg="No non-localhost DNS nameservers are left in resolv.conf. Using default external servers : [nameserver 8.8.8.8 nameserver 8.8.4.4]"
time="2016-04-18T11:06:48.802319599+02:00" level=info msg="IPv6 enabled; Adding default IPv6 external servers : [nameserver 2001:4860:4860::8888 nameserver 2001:4860:4860::8844]"
time="2016-04-18T11:06:49.279474450+02:00" level=info msg="Layer sha256:0ed68184d16f592b2b669196ddd239e23c13ab6511515503920f8ee031532c3b cleaned up"
time="2016-04-18T11:06:49.410528665+02:00" level=info msg="Layer sha256:0ed68184d16f592b2b669196ddd239e23c13ab6511515503920f8ee031532c3b cleaned up"
time="2016-04-18T11:06:49.538699754+02:00" level=info msg="Layer sha256:0ed68184d16f592b2b669196ddd239e23c13ab6511515503920f8ee031532c3b cleaned up"
time="2016-04-18T11:07:05.061426191+02:00" level=info msg="Layer sha256:43f9abb24f57edceb92fe8b6a2af87abd4e399a05b6c5c073e0df1aac6619092 cleaned up"
time="2016-04-18T11:07:05.161393834+02:00" level=info msg="Layer sha256:43f9abb24f57edceb92fe8b6a2af87abd4e399a05b6c5c073e0df1aac6619092 cleaned up"
time="2016-04-18T11:07:05.262665513+02:00" level=info msg="Layer sha256:43f9abb24f57edceb92fe8b6a2af87abd4e399a05b6c5c073e0df1aac6619092 cleaned up"
time="2016-04-18T11:07:05.374500416+02:00" level=info msg="No non-localhost DNS nameservers are left in resolv.conf. Using default external servers : [nameserver 8.8.8.8 nameserver 8.8.4.4]"
time="2016-04-18T11:07:05.374557504+02:00" level=info msg="IPv6 enabled; Adding default IPv6 external servers : [nameserver 2001:4860:4860::8888 nameserver 2001:4860:4860::8844]"
time="2016-04-18T11:09:58.102890619+02:00" level=error msg="Handler for GET /v1.22/networks/europe_default returned error: network europe_default not found"
time="2016-04-18T11:09:58.440307296+02:00" level=info msg="No non-localhost DNS nameservers are left in resolv.conf. Using default external servers : [nameserver 8.8.8.8 nameserver 8.8.4.4]"
time="2016-04-18T11:09:58.440335145+02:00" level=info msg="IPv6 enabled; Adding default IPv6 external servers : [nameserver 2001:4860:4860::8888 nameserver 2001:4860:4860::8844]"
time="2016-04-18T11:10:38.048770865+02:00" level=error msg="restartmanager canceled"
time="2016-04-18T11:10:39.586605651+02:00" level=info msg="No non-localhost DNS nameservers are left in resolv.conf. Using default external servers : [nameserver 8.8.8.8 nameserver 8.8.4.4]"
time="2016-04-18T11:10:39.586650371+02:00" level=info msg="IPv6 enabled; Adding default IPv6 external servers : [nameserver 2001:4860:4860::8888 nameserver 2001:4860:4860::8844]"
time="2016-04-18T11:10:39.897137839+02:00" level=info msg="No non-localhost DNS nameservers are left in resolv.conf. Using default external servers : [nameserver 8.8.8.8 nameserver 8.8.4.4]"
time="2016-04-18T11:10:39.897189809+02:00" level=info msg="IPv6 enabled; Adding default IPv6 external servers : [nameserver 2001:4860:4860::8888 nameserver 2001:4860:4860::8844]"
time="2016-04-18T11:10:40.293406976+02:00" level=info msg="No non-localhost DNS nameservers are left in resolv.conf. Using default external servers : [nameserver 8.8.8.8 nameserver 8.8.4.4]"
time="2016-04-18T11:10:40.293454935+02:00" level=info msg="IPv6 enabled; Adding default IPv6 external servers : [nameserver 2001:4860:4860::8888 nameserver 2001:4860:4860::8844]"
time="2016-04-18T11:10:40.343128706+02:00" level=warning msg="Auto-creating non-existent volume host path /src/europe/watcher/gates, this is deprecated and will be removed soon"
time="2016-04-18T11:10:40.668679456+02:00" level=info msg="No non-localhost DNS nameservers are left in resolv.conf. Using default external servers : [nameserver 8.8.8.8 nameserver 8.8.4.4]"
time="2016-04-18T11:10:40.668728940+02:00" level=info msg="IPv6 enabled; Adding default IPv6 external servers : [nameserver 2001:4860:4860::8888 nameserver 2001:4860:4860::8844]"
time="2016-04-18T11:10:40.865816243+02:00" level=error msg="Handler for GET /v1.22/images/nginx/json returned error: No such image: nginx"
time="2016-04-18T11:10:41.980522880+02:00" level=error msg="Error trying v2 registry: Get https://registry-1.docker.io/v2/library/nginx/manifests/latest: dial tcp 54.88.172.196:443: connect: network is unreachable"
time="2016-04-18T11:10:41.980590387+02:00" level=error msg="Attempting next endpoint for pull after error: Get https://registry-1.docker.io/v2/library/nginx/manifests/latest: dial tcp 54.88.172.196:443: connect: network is unreachable"
time="2016-04-18T11:10:41.980652971+02:00" level=error msg="Handler for POST /v1.22/images/create returned error: Get https://registry-1.docker.io/v2/library/nginx/manifests/latest: dial tcp 54.88.172.196:443: connect: network is unreachable"
time="2016-04-18T11:16:12.094499530+02:00" level=info msg="No non-localhost DNS nameservers are left in resolv.conf. Using default external servers : [nameserver 8.8.8.8 nameserver 8.8.4.4]"
time="2016-04-18T11:16:12.094544754+02:00" level=info msg="IPv6 enabled; Adding default IPv6 external servers : [nameserver 2001:4860:4860::8888 nameserver 2001:4860:4860::8844]"
time="2016-04-18T11:16:12.241954486+02:00" level=error msg="Handler for GET /v1.22/images/nginx/json returned error: No such image: nginx"
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

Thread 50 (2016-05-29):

Problémy během muzejní noci

msgre, 2016-05-29:
Kolem 23:20 se Evropa sama vypnula a nepodařilo se ji znovu nahodit. Podle logu jsem nenašel zjevnou příčinu. Těsně před pádem se ale v syslogu objevují bloky, které vedou k TV a HDMI. Možná za to může CEC driver, možná telina, možná horko v nevětraném panelu. V neděli jsem to zašel občíhnout a po nastartování vůbec nenajel obraz. NUC jsem vypnul (dlouhé podržení power buttonu), znovu zapnul a všechno zase fungovalo normálně (páteční pokusy o oživení se řešily přes vytáhnutí NUCu ze zásuvky, žádné korektní ukončení se neřešilo).

Kromě problémů s "monitorem" jsem v logu z Dockeru zachytil spílání nad deskou číslo 1. Při nedělním prověření se ale chovala stabilně. Budem ji dál sledovat.

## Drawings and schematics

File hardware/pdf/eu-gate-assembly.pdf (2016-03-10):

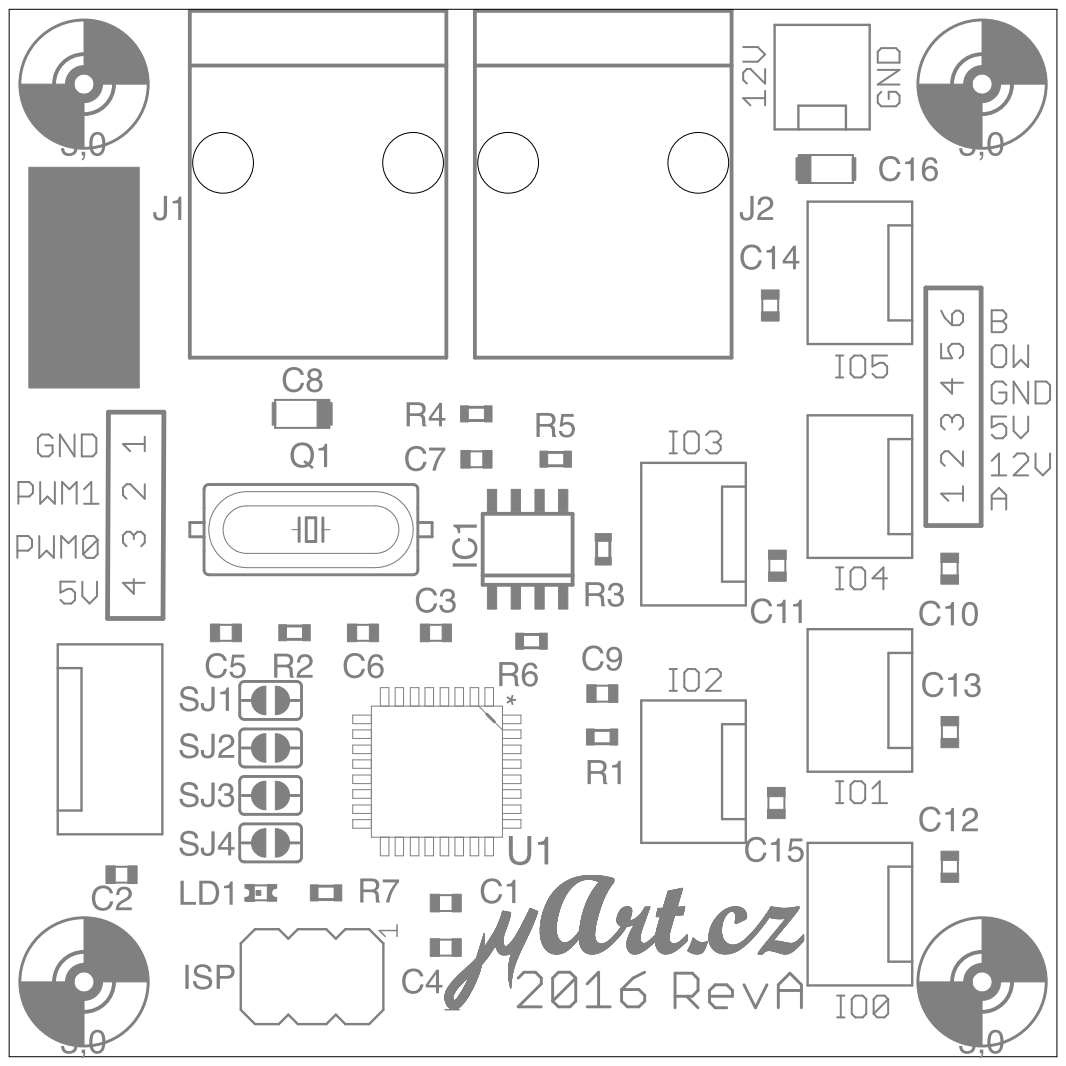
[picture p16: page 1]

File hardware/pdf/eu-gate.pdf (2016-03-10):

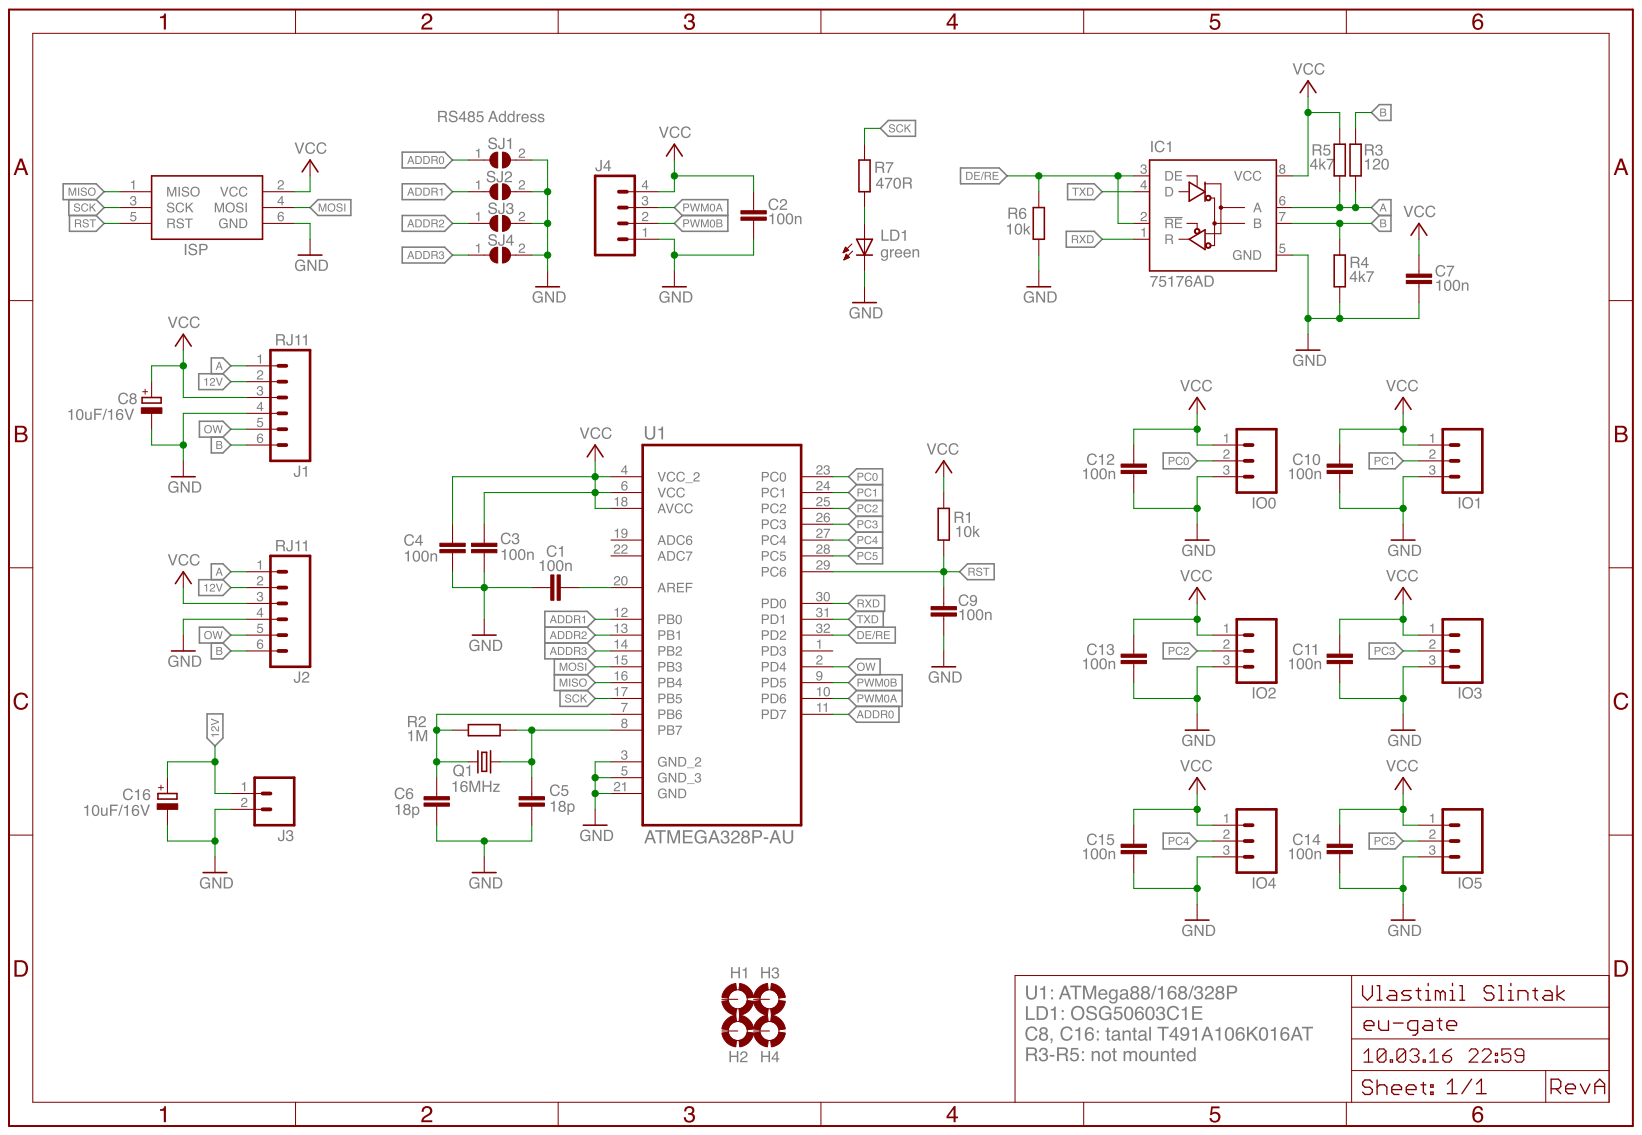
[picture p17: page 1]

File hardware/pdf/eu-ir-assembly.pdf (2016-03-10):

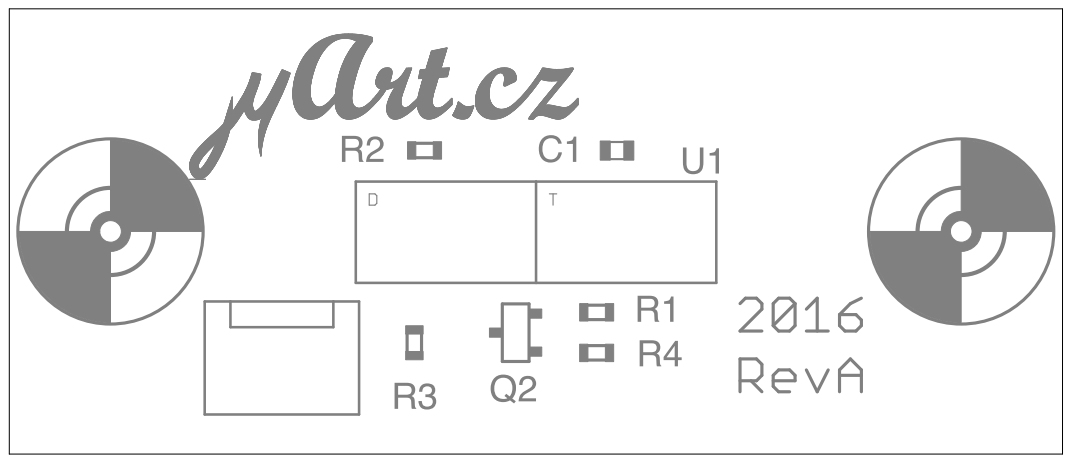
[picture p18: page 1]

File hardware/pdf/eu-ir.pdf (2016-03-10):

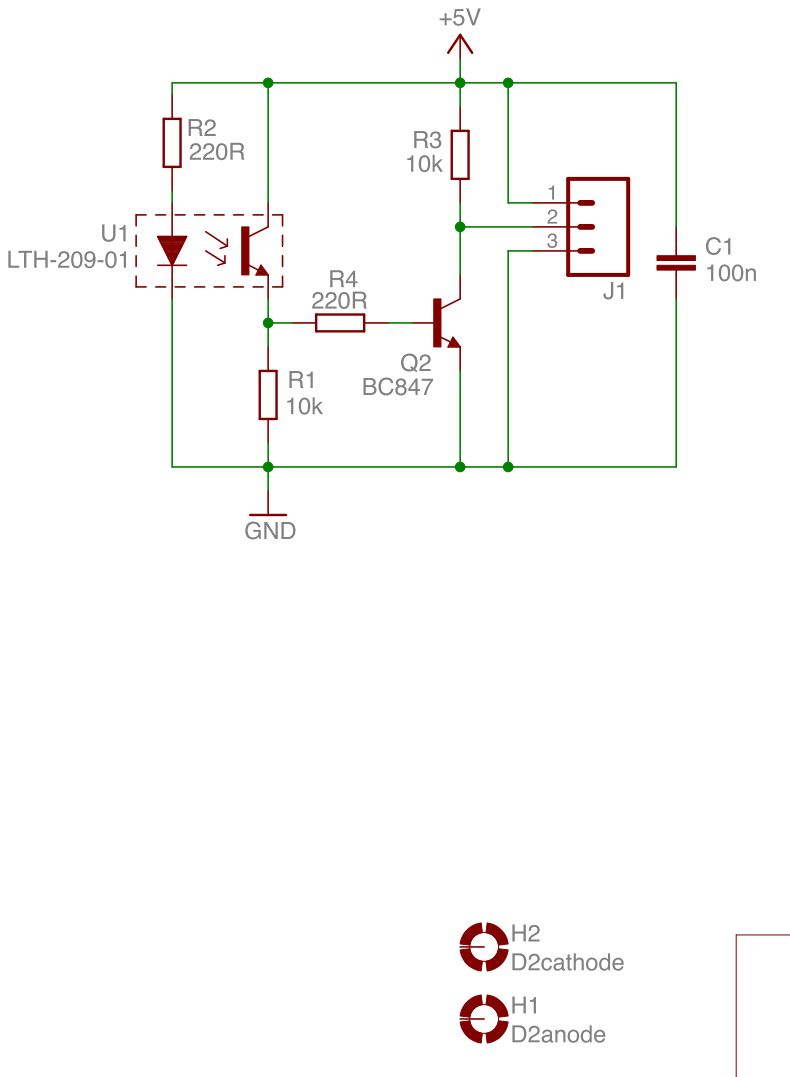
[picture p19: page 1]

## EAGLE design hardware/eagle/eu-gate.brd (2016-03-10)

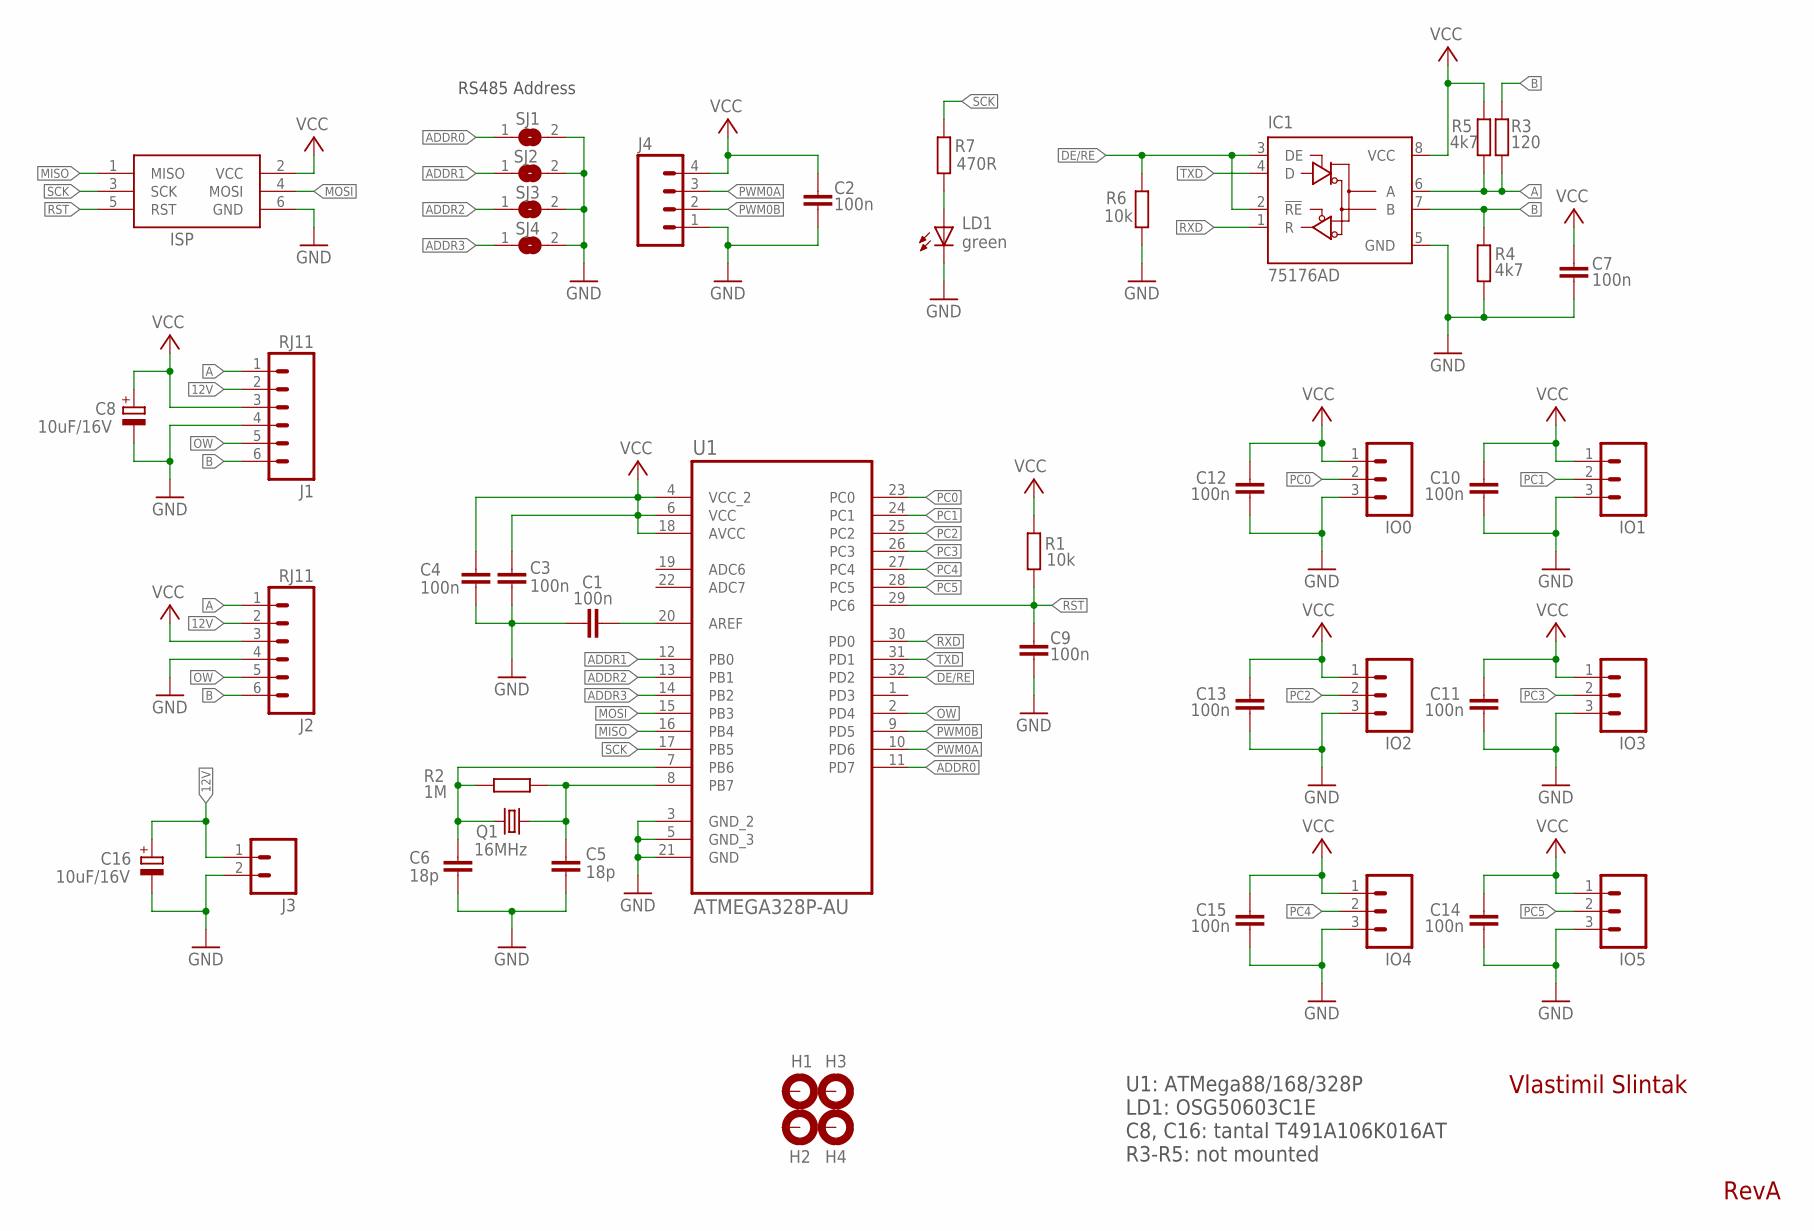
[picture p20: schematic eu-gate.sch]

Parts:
C1, C2, C3, C4, C7, C9, C10, C11, C12, C13, C14, C15: 100n; C0603
C5, C6: 18p; C0603
C8, C16: 10uF/16V; SMC_A
H1, H2, H3, H4: MOUNT-PAD-ROUND3.0; 3,0-PAD
IC1: 75176AD; D_R-PDSO-G8
IO0, IO1, IO2, IO3, IO4, IO5: M03POLAR; MOLEX-1X3
ISP: AVRISP-6; AVRISP
J1, J2: RJ11; RJ11-6
J3: M02POLAR; MOLEX-1X2
J4: M04POLAR; MOLEX-1X4
LD1: green; CHIPLED_0603
Q1: 16MHz; HC49UP
R1, R6: 10k; R0603
R2: 1M; R0603
R3: 120; R0603
R4, R5: 4k7; R0603
R7: 470R; R0603
SJ1, SJ2, SJ3, SJ4: SJ
U1: ATMEGA328P-AU; 32TQFP

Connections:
12V: C16.+, J1.2, J2.2, J3.1
A: IC1.6 (A), J1.1, J2.1, R3.2, R5.1
ADDR0: SJ1.1, U1.11 (PD7)
ADDR1: SJ2.1, U1.12 (PB0)
ADDR2: SJ3.1, U1.13 (PB1)
ADDR3: SJ4.1, U1.14 (PB2)
B: IC1.7 (B), J1.6, J2.6, R3.1, R4.2
DE/RE: IC1.2 (!RE), IC1.3 (DE), R6.2, U1.32 (PD2)
GND: C1.1, C2.1, C3.1, C4.1, C5.2, C6.2, C7.2, C8.-, C9.1, C10.1, C11.1, C12.1, C13.1, C14.1, C15.1, C16.-, IC1.5 (GND), IO0.3, IO1.3, IO2.3, IO3.3, IO4.3, IO5.3, ISP.6 (GND), J1.4, J2.4, J3.2, J4.1, LD1.C, R4.1, R6.1, SJ1.2, SJ2.2, SJ3.2, SJ4.2, U1.3 (GND_2), U1.5 (GND_3), U1.21 (GND)
MISO: ISP.1 (MISO), U1.16 (PB4)
MOSI: ISP.4 (MOSI), U1.15 (PB3)
unnamed: C1.2, U1.20 (AREF)
unnamed: LD1.A, R7.1
unnamed: C5.1, Q1.1, R2.2, U1.8 (PB7)
OW: J1.5, J2.5, U1.2 (PD4)
PC0: IO0.2, U1.23 (PC0)
PC1: IO1.2, U1.24 (PC1)
PC2: IO2.2, U1.25 (PC2)
PC3: IO3.2, U1.26 (PC3)
PC4: IO4.2, U1.27 (PC4)
PC5: IO5.2, U1.28 (PC5)
PWM0A: J4.3, U1.10 (PD6)
PWM0B: J4.2, U1.9 (PD5)
RST: C9.2, ISP.5 (RST), R1.1, U1.29 (PC6)
RXD: IC1.1 (R), U1.30 (PD0)
SCK: ISP.3 (SCK), R7.2, U1.17 (PB5)
TXD: IC1.4 (D), U1.31 (PD1)
VCC: C2.2, C3.2, C4.2, C7.1, C8.+, C10.2, C11.2, C12.2, C13.2, C14.2, C15.2, IC1.8 (VCC), IO0.1, IO1.1, IO2.1, IO3.1, IO4.1, IO5.1, ISP.2 (VCC), J1.3, J2.3, J4.4, R1.2, R5.2, U1.4 (VCC_2), U1.6 (VCC), U1.18 (AVCC)
XYZ: C6.1, Q1.2, R2.1, U1.7 (PB6)

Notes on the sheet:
R3-R5: not mounted
C8, C16: tantal T491A106K016AT
LD1: OSG50603C1E
RS485 Address
U1: ATMega88/168/328P

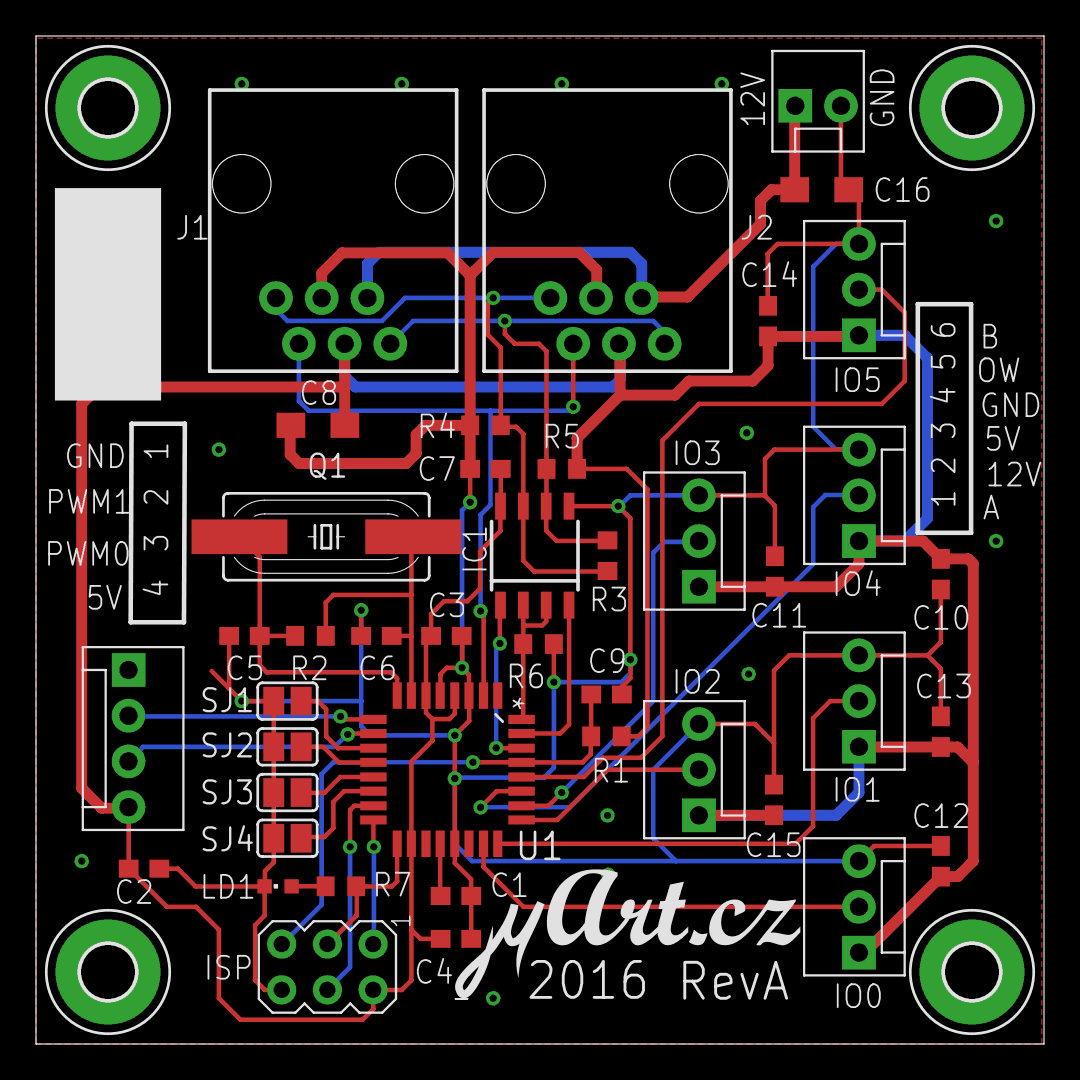
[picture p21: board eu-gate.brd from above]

Board: 2 copper layers, 56.0 x 56.0 mm, 47 parts (0 on the bottom side), 29 nets.

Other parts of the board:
U$1: UART-LOGO

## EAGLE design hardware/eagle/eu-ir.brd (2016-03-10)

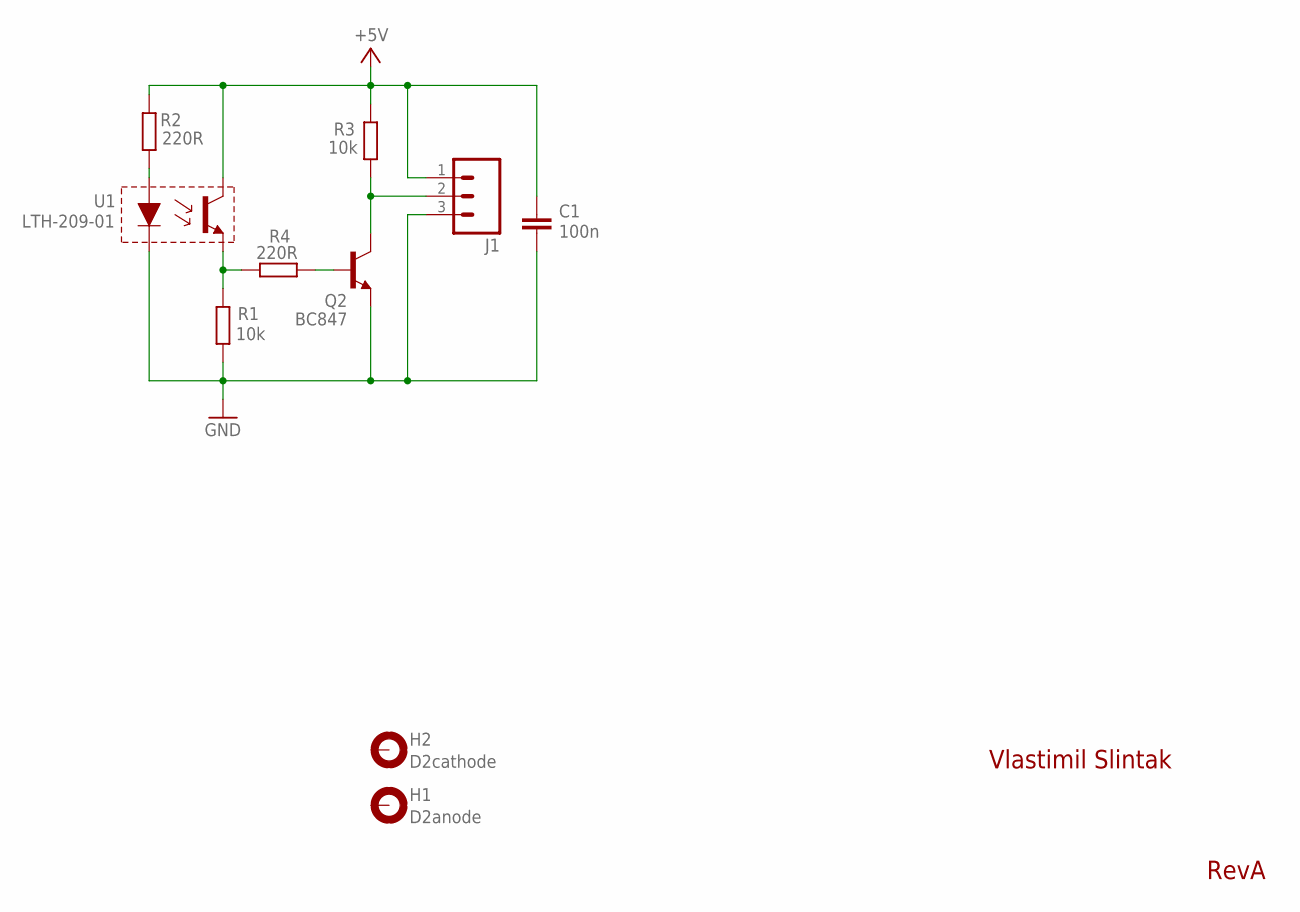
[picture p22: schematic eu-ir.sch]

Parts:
C1: 100n; C0603
H1: D2anode; 4,1-PAD
H2: D2cathode; 4,1-PAD
J1: M03POLAR; MOLEX-1X3
Q2: BC847; SOT23
R1, R3: 10k; R0603
R2, R4: 220R; R0603
U1: LTH-209-01; LTH209

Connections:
+5V: C1.1, J1.1, R2.2, R3.1, U1.T4 (C)
GND: C1.2, J1.3, Q2.2 (E), R1.1, U1.D2 (D-)
unnamed: R2.1, U1.D1 (D+)
unnamed: R1.2, R4.2, U1.T3 (E)
unnamed: J1.2, Q2.3 (C), R3.2
unnamed: Q2.1 (B), R4.1

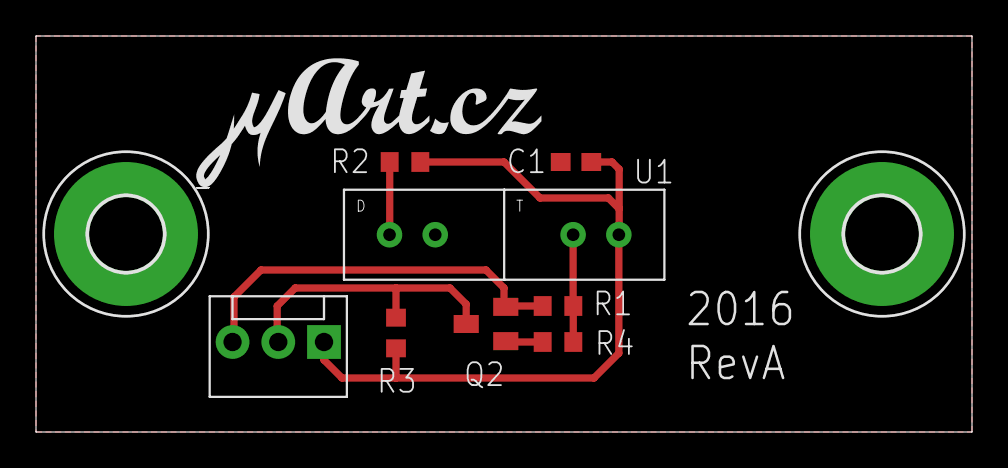
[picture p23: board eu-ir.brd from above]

Board: 2 copper layers, 52.0 x 22.0 mm, 11 parts (0 on the bottom side), 6 nets.

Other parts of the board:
U$1: UART-LOGO

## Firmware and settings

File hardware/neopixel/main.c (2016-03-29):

/*******************************************************************************
 * Neopixel firmware for Europe's gate board.
 * Implemented for ATMegaXX8P.
 *
 * The WS2812 functions are modified https://github.com/cpldcpu/light_ws2812
 *
 * Date: 28MAR2016
 * Author: Vlastimil Slintak <slintak@uart.cz>
 ******************************************************************************/

#include <inttypes.h>
#include <stdlib.h>
#include <string.h>
#include <avr/io.h>
#include <avr/wdt.h>
#include <avr/interrupt.h>
#include <util/delay.h>

#include "config.h"
#include "rs485.h"
#include "modbus.h"
#include "timers.h"
#include "gpio.h"
#include "ws2812.h"

#define MODBUS_BASIC_REGISTERS 3
#define MODBUS_REG_INPUTS 0
#define MODBUS_REG_HWFW_VERSION 1
#define MODBUS_REG_RESET 2
static uint16_t mb_basic_registers[MODBUS_BASIC_REGISTERS];
static uint8_t mb_basic_registers_change[MODBUS_BASIC_REGISTERS];

static uint16_t mb_ws2812_registers[WS2812_NUM];
static uint8_t mb_ws2812_registers_change[WS2812_NUM];

#define MB_ADDRESS_REGIONS 2
static mb_registers_t mb_registers[] = {
    // Basic registers -- inputs, version, reset.
    {0x0000, MODBUS_BASIC_REGISTERS, mb_basic_registers, mb_basic_registers_change},
    // WS2812 LEDs -- color, brightness.
    {0x1000, WS2812_NUM, mb_ws2812_registers, mb_ws2812_registers_change}
};

static uint8_t leds_update;
struct cRGB leds[WS2812_NUM];

int main(void) {
    wdt_reset();
    wdt_enable(WDTO_8S);

    // Set address pins as inputs.
    wdt_reset();
    MODBUS_ADDRESS_INIT();

    // Initialize RS485/UART interface.
    wdt_reset();
    rs485_init();

    // Initialize WS2812 (Neopixel). Turn off all LEDs.
    wdt_reset();
    memset((uint8_t *)leds, 0, sizeof(leds));
    ws2812_setleds(leds, WS2812_NUM);
    leds_update = 0;

    // Start milliseconds timer.
    wdt_reset();
    timer1_init();

    // Initialize modbus.
    uint8_t slave = MODBUS_ADDRESS_READ();
    modbus_init(slave, mb_registers, MB_ADDRESS_REGIONS);

    // Write HW and FW versions into modbus register.
    mb_basic_registers[MODBUS_REG_HWFW_VERSION] = (HW_VERSION << 12) | (FW_VERSION);

    // Blink onboard LED.
    wdt_reset();
    LED_INIT();
    for(uint8_t i = 0; i < LED_RESTART_BLINK; i++) {
        LED_ON();
        _delay_ms(10);
        LED_OFF();
        _delay_ms(50);
    }

    // Enable interrupts.
    sei();

    #ifdef DEBUG_MAIN
    rs485_putp(PSTR("Modbus addr: 0x"));
    rs485_puthex2(slave);
    rs485_putp(PSTR("\nUp and running.\n"));
    #endif

    while(1) {
        // Main modbus loop.
        modbus_loop();

        // Reset
        if(mb_basic_registers_change[MODBUS_REG_RESET] == MODBUS_REGS_WRITE) {
            rs485_flush();
            wdt_reset();
            wdt_disable();
            wdt_enable(WDTO_500MS);
            while(1);
        }

        // Check if any LED settings changed. If so, send it to WS2812.
        for(uint8_t i = 0; i < WS2812_NUM; i++) {
            if(mb_ws2812_registers_change[i] == MODBUS_REGS_WRITE) {
                mb_ws2812_registers_change[i] = MODBUS_REGS_NOT_CHANGED;

                // One Modbus register contains RGB and brightness (L).
                // Register is 0xLRGB, modbus has different endianess than AVR,
                // thus our data have format - 0xGBLR.
                uint8_t brightness = ((mb_ws2812_registers[i] >> 4) & 0x0F) + 1;
                leds[i].r = ((mb_ws2812_registers[i] >> 0) & 0x0F) * brightness;
                leds[i].g = ((mb_ws2812_registers[i] >> 12) & 0x0F) * brightness;
                leds[i].b = ((mb_ws2812_registers[i] >> 8) & 0x0F) * brightness;
                leds_update = 1;
                LED_ON();
            }
        }

        // If any LED changed, send new data to WS2812.
        if(leds_update) {
            ws2812_sendarray((uint8_t *)leds, WS2812_NUM*3);
            leds_update = 0;
            LED_OFF();
        }

        wdt_reset();
    }

    while(1); // Code should not reach here!
    return 0;
}

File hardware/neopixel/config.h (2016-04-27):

#ifndef __IR_CONFIG_H__
#define __IR_CONFIG_H__

#define FW_VERSION 0x010UL
#define HW_VERSION 0x1UL

/******************************************************************************/
/** RS485 config **************************************************************/

/**
 * Baudrate for UART1.
 */
#define BAUD_RATE 57600

/**
 * Registers and pin number for RS485/UART direction.
 * Output -> high
 * Input  -> low
 *
 * This pin has pull-down resistor, thus default direction is input.
 */
#define RS485_DIR_PORT PORTD
#define RS485_DIR_DDR  DDRD
#define RS485_DIR_PIN  PD2

/**
 * RX buffer size for RS485 (UART).
 * In bytes.
 */
#define RS485_BUFFER_SIZE 128

/******************************************************************************/
/** LED config ****************************************************************/

/**
 * How many times should LED blink after the restart.
 */
#define LED_RESTART_BLINK 3

/**
 * Number of WS2812 (Neopixel) LEDs.
 */
#define WS2812_NUM 48

/**
 * Data port where WS2812 are connected.
 */
#define WS2812_PORT D

/**
 * Pin number with WS2812.
 */
#define WS2812_PIN  6

/******************************************************************************/
/** Debug output **************************************************************/

/**
 * Debug informations printed to UART0.
 */
// #define DEBUG_MAIN
// #define DEBUG_IR
// #define DEBUG_MODBUS
// #define DEBUG_MODBUS_VERBOSE

/******************************************************************************/
/** Aux macros. Do not change! ************************************************/

// All our PROGMEM data is in the same extended range as the FLASHEND
#include <avr/pgmspace.h>
#if defined(__AVR_ATmega1284P__)
#define pgm_read_byte_progmem(ptr) pgm_read_byte_far((FLASHEND&0xFFFF0000)|(uint16_t)(ptr))
#elif defined(__AVR_ATmega328P__) || defined(__AVR_ATmega168P__) || defined(__AVR_ATmega88P__)
#define pgm_read_byte_progmem(ptr) pgm_read_byte((uint16_t)(ptr))
#endif

#define hex(digit) ((digit)+((digit)>9?'A'-10:'0'))

#define MAX(x, y) (((x) > (y)) ? (x) : (y))
#define MIN(x, y) (((x) < (y)) ? (x) : (y))

#define BAUD ((F_CPU/(BAUD_RATE*8L)-1)/2)
#define BAUD_DOUBLE ((F_CPU/(BAUD_RATE*8L))-1)

#endif

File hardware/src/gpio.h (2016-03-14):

#ifndef __EU_GPIO_H__
#define __EU_GPIO_H__

// Onboard green LED.
#define LED_GRN PB5
#define LED_INIT() DDRB |= _BV(LED_GRN)
#define LED_ON()   PORTB |= _BV(LED_GRN)
#define LED_OFF()  PORTB &= ~_BV(LED_GRN)
#define LED_TOGGLE() PORTB ^= _BV(LED_GRN)

// Pin definitions for all 6 inputs.
#define IR_DDR  DDRC
#define IR_PIN  PINC
#define IR_PORT PORTC
#define IR_IOS  0x3F
#define IR_IO0  _BV(PC0)
#define IR_IO1  _BV(PC1)
#define IR_IO2  _BV(PC2)
#define IR_IO3  _BV(PC3)
#define IR_IO4  _BV(PC4)
#define IR_IO5  _BV(PC5)
#define IR_ALL  (IR_IO0 | IR_IO1 | IR_IO2 | IR_IO3 | IR_IO4 | IR_IO5)
// Set all pins as output and activate pullups.
#define IR_INIT() IR_DDR &= ~IR_ALL; IR_PORT |= IR_ALL


#define PCINT_ENABLE()  (PCICR |= _BV(PCIE1))
#define PCINT_DISABLE() (PCICR &= ~_BV(PCIE1))

/**
 * Initialize all inputs and enable pinchange interrupt.
 */
void gpio_init(void);

/**
 * Read states of all inputs and debouncing.
 */
uint8_t gpio_loop(void);

#endif

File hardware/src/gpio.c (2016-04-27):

#include <stdint.h>
#include <avr/io.h>
#include <avr/interrupt.h>

#include "config.h"
#include "rs485.h"
#include "timers.h"
#include "gpio.h"

static uint8_t gpio_new_state;
static uint32_t gpio_new_state_time;

static uint8_t gpio_tmp = 0;
static uint32_t gpio_now = 0;

/**
 * Pin change interrupt 1 (for PCINT8 - PCINT13).
 */
ISR(PCINT1_vect) {
    // Gates are active low.
    gpio_new_state = ~IR_PIN & IR_ALL;
    gpio_new_state_time = timer1_get();
    PCINT_DISABLE();
}

 void gpio_init(void) {
    // Enable interrupt 1 for pin change.
    PCINT_ENABLE();
    // Enable interrupt for each pin.
    PCMSK1 |= _BV(PCINT8) | _BV(PCINT9) | _BV(PCINT10);
    PCMSK1 |= _BV(PCINT11) | _BV(PCINT12) | _BV(PCINT13);

    // Set PC0-PC5 as inputs.
    IR_INIT();

    gpio_new_state = 0;
    gpio_new_state_time = 0;
 }

uint8_t gpio_loop(void) {
    #ifndef IR_KEYBOARD_MODE
        gpio_now = timer1_get();
        if((gpio_now - gpio_new_state_time) > IR_DEBOUNCE_TIME) {
            // Re-enable PCINT from IR inputs after some "debounce" time.
            PCINT_ENABLE();
            gpio_tmp = 0;
            LED_OFF();
        } else {
            gpio_tmp = gpio_new_state;
            if(gpio_tmp) {
                #ifdef DEBUG_MAIN
                rs485_puthex4(gpio_now);
                rs485_putp(PSTR(": GPIO "));
                rs485_puthex2(gpio_tmp);
                rs485_putc('\n');
                #endif

                LED_ON();
                gpio_new_state = 0;
            }
        }
    #else
        gpio_tmp = gpio_new_state;
        if(gpio_tmp) {
            LED_ON();
        } else {
            LED_OFF();
        }
        PCINT_ENABLE();
    #endif

    return gpio_tmp;
}

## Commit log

2016-01-30 Time settings from Category model is now correctly passed into Javascript application, so questions from easy categories have much longer time to answer.
    [models.py, serializers.py, views.py]
2016-01-30 Final screen with result of current game
2016-03-10 hardware: eagle schematics for gate and IR boards
    [eu-gate.brd, eu-gate.sch, eu-ir.brd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]
2016-03-10 hardware: gerber outputs
    [bot.gbr, dim.gbr, mill.gbr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]
2016-03-10 hardware: schematics, assembly documentation and BOM
2016-03-11 hardwares: IR wire photos
2016-03-11 hardware: wires description in README
2016-03-25 Country model now have attributes to identify HW boards on gamedesk -- board and gate ID
2016-03-28 hardware: support for ATMega88P MCU and fixed modbus address
    [config.h]
2016-04-01 Field for LED number in Country model
2016-04-06 Tuned Neopixel effects on watcher script. Now is possible to raise LED effects with Websocket message.
2016-04-07 All Neopixel effects ready -- rainbow during intro, flash/noise during countdown, blink during game/results
    [serializers.py]
2016-04-11 SVG icons for categories and buttons in game
2016-04-11 Players must have at least half of correct answers to make record in top scores
    [views.py]
2016-04-12 Ooops, fresh crossbar dependencies broke our Docker image, lets pin it.
2016-04-12 Turn LED off in devel environment of docker-compose
2016-04-13 Initial data for description and curiosity category
    [popis.csv, zajimavosti.csv]
2016-04-13 Modified handling with high scores, solved #36
    [admin.py, models.py, serializers.py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]
2016-04-14 Back to slim buttons on gamemode screen
2016-04-14 Commented board/gate hint with right answer
2016-04-16 Final set of board/gate combination
2016-04-18 Updated list of production boards for watcher script
2016-04-18 Updated migration with production board/gate combination
2016-04-18 Unique combination of board/gate
2016-04-18 Models for 3D prints.
    [reflector-holder-pin.stl, reflector-holder.f3d, reflector-holder.stl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]
2016-04-18 Renamed folder with 3d objects
    [reflector-holder-pin.stl, reflector-holder.f3d, reflector-holder.stl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]
2016-04-19 Bug in get_random_questions method
    [models.py]
2016-04-19 Production set of LEDs
2016-04-19 LED number for last country fixed
2016-04-22 Finalized set of questions for opening ceremony
    [popis.csv, zajimavosti.csv]
2016-04-25 hardware: neopixel FW with 48 LEDs and for ATMega88
2016-04-27 Watcher script now make reboot flag file upon pressing poweroff button on keyboard gate
2016-04-27 Change docker compose confs for -- content for all, nuc with enabled LED
2016-05-05 Infinite moving on result alphabet, by pressing left button on last letter cursor will move to first letter
2016-09-11 hardware: connection of RS485 cable
2017-12-03 docs: Bottom part of boardgame photos.

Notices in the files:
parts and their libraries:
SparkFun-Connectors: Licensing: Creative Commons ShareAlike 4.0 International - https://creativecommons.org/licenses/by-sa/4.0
